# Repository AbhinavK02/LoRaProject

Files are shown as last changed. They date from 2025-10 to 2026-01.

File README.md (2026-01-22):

# LoRaProject
## Introduction
All people have a lot to do and may not always have time to check their mailbox.
Imagine how long some letters are left in the mailbox for days just because one is too busy. On the
other hand, checking your mailbox only to find nothing is quite frustrating. What if there was a way
that your mailbox could tell you when there is mail? What if you had a talking mailbox?
To solve this problem, we introduce The Talking Mailbox. The aim of The Talking Mailbox project
is to design and assemble a system that can detect the presence of mail within a mailbox and notify the owner of the mailbox.

The full project report can be found here: [Project Report](<Project Report - Talking Mailbox.pdf?raw=true>)

Talking Mailbox Product Showcase (https://www.youtube.com/watch?v=1nNW60RcUi4)

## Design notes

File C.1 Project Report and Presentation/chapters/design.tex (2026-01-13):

\section{Methodology and Design}
\label{sec: methodologyAndDesign}
%%%%%%%%%%%%%%%%%%%%%%%%%%%%%%%%%%%%%%%%%%%%%%%%%%%%%%%%%%%%%%%%%%%%%%%%%%%%%%%%%%%%%%%%%%%%%%%%%%%%%%%%%%%%%%%%%%%%%%%%
% \subsection{Design Approach}
% \label{sec: designApproach}
% The design approach used in this project was a simple waterfall model. After a deliverable was completed, the next deliverable was started. This can be clearly seen in Figure \ref{fig: ganttChart}. The only exception to this model was during the Software Development and Project Implementation Deliverables (which are discussed in Section \ref{sec: implementation}) where some iterative testing and debugging was employed. The testing methods are discussed in Section \ref{sec: validationMethod}.
%%%%%%%%%%%%%%%%%%%%%%%%%%%%%%%%%%%%%%%%%%%%%%%%%%%%%%%%%%%%%%%%%%%%%%%%%%%%%%%%%%%%%%%%%%%%%%%%%%%%%%%%%%%%%%%%%%%%%%%%
\subsection{System Layer}
\label{sec: systemLayer}

\subsubsection{System Architecture}
The complete functional structure diagram of the system is shown in \ref{fig: fsd}. This illustrates the highest level of the systems design and the different modules which were created to fulfil the requirements. The complete design and revision history can also be found in the project repository on GitHub following this link \url{https://github.com/AbhinavK02/LoRaProject}.
\label{sec: systemArchitechture}
\begin{figure}[h!]
    \centering
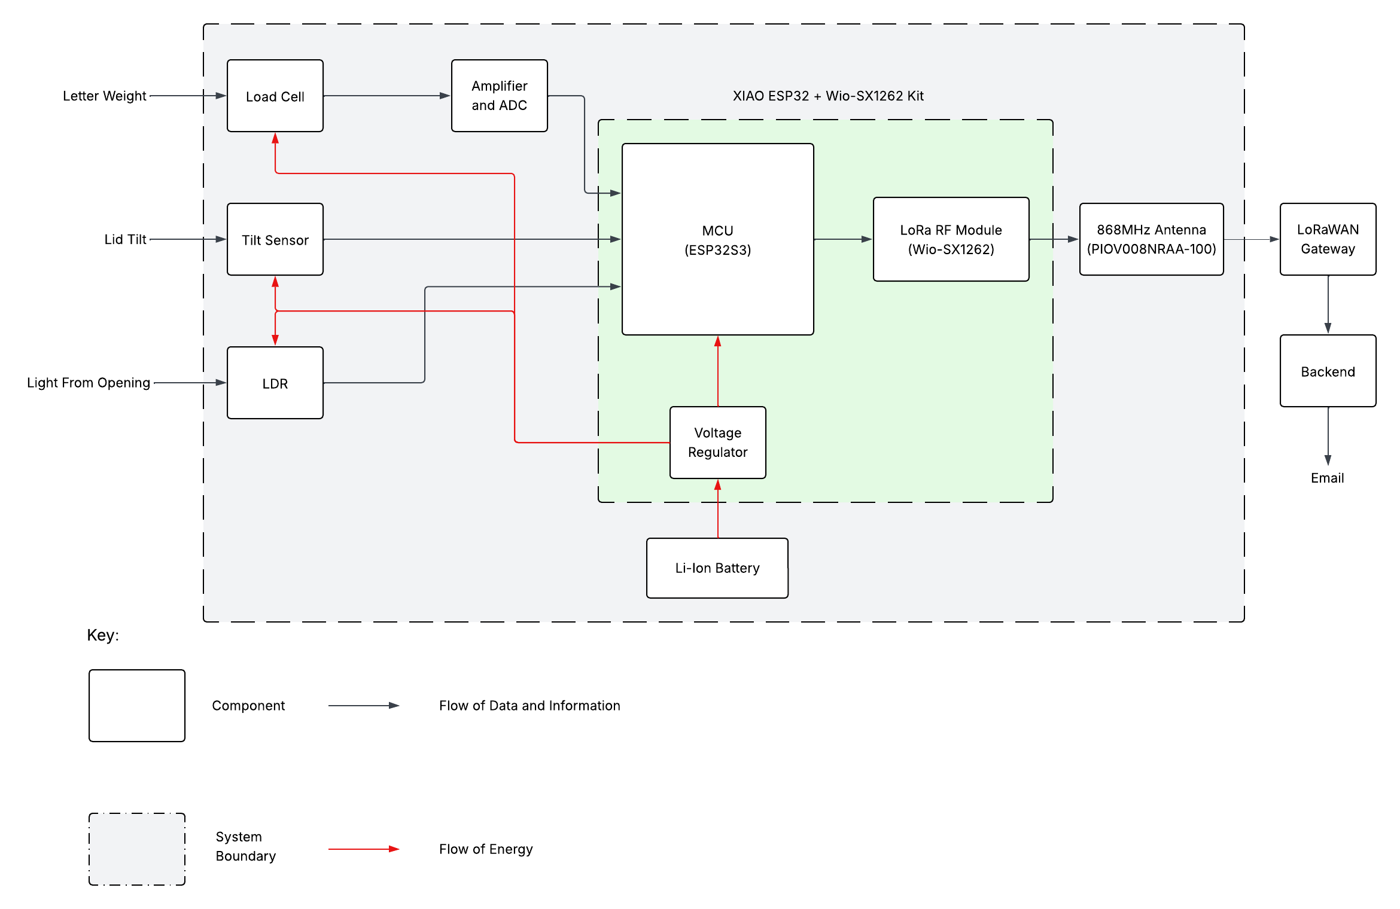
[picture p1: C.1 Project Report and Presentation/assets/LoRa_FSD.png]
    
    \caption{Functional Structure Diagram of the System Architecture}
    \label{fig: fsd}
\end{figure}
\pagebreak

\subsubsection{Bill of Materials}
\label{sec: billOfMaterials}
This is an estimate of the materials required to make this project, these are all over estimates, as all components/materials except 2.1 - 2.6 were used from the university stock.
\begin{table}[h]
    \centering
    \begin{tabular}{|c|l|p{2.8cm}|c|l|r|}
        \hline
        \textbf{Item} & \textbf{Part} & \textbf{Description} & \textbf{Qty} & \textbf{Notes} & \textbf{Total Price (€)} \\ \hline
        
        \rowcolor[gray]{0.9} \multicolumn{6}{|l|}{\textbf{1.0 Mechanical Components}} \\ \hline
        1.1 & Top Plate & Detection Plate & 1 & Wood (40x30x0.5cm) & 5.00 \\ \hline
        1.2 & Bottom Plate & Base for load cell & 1 & Wood (15x15x0.5cm) & 3.00 \\ \hline
        1.3 & M4 Screw & Top plate screw & 2 & - & 1.00 \\ \hline
        1.4 & M5 Hex Nut & Height spacer nut & 4 & - & 0.50 \\ \hline
        1.5 & M5 Screw & Bottom plate screw & 2 & - & 1.00 \\ \hline
        1.6 & M6 Hex Nut & Height spacer nut & 4 & - & 0.50 \\ \hline
        1.7 & Misc. & Tape, Glue & - & - & 0.50 \\ \hline
        
        \rowcolor[gray]{0.9} \multicolumn{6}{|l|}{\textbf{2.0 Electrical Components}} \\ \hline
        2.1 & Load Cell + HX711 & Load cell + Amplifier module & 1 & JOY-IT & 6.40 \\ \hline
        2.2 & Tilt Switch & Ball tilt switch & 1 & IDUINO & 0.94 \\ \hline
        2.3 & LDR & Light resistor & 1 & SERTRONICS & 1.35 \\ \hline
        2.4 & Battery & 1800 mAh Li-Ion & 1 & SOLDERED & 10.24 \\ \hline
        2.5 & MCU + LoRa & Xiao ESP32 + SX1262 & 1 & Seeedstudio & 11.68 \\ \hline
        2.6 & Antenna & Long range antenna & 1 & Amphenol-SAA & 2.69 \\ \hline
        2.7 & 1 kOhm resistor & Through Hole & 1 & YAGEO & 0.10 \\ \hline
        2.8 & 2 kOhm resistor & Through Hole & 1 & YAGEO & 0.10 \\ \hline
        2.9 & Wires & Jumper wires of different length & - & - & 0.30 \\ \hline
        2.10 & Misc. & Breadboard, Wire Sleeves, Solder & - & - & 0.50 \\ \hline
        \hline
        \multicolumn{5}{|r|}{Tax (VAT 20\%)} & 9.16 \\ \hline
        \multicolumn{5}{|r|}{\textbf{Grand Total (€)}} & \textbf{54.96} \\ \hline
        % for any changes check and adjust the BOM excel file
    \end{tabular}
    \caption{Combined Mechanical and Electrical Bill of Materials with Total Cost}
    \label{tab: bom}
\end{table}

%%%%%%%%%%%%%%%%%%%%%%%%%%%%%%%%%%%%%%%%%%%%%%%%%%%%%%%%%%%%%%%%%%%%%%%%%%%%%%%%%%%%%%%%%%%%%%%%%%%%%%%%%%%%%%%%%%%%%%%%
\subsection{Hardware Layer}
\label{sec: HWLayer}
\subsubsection{Load Cell Assembly}
\label{sec: 3dDesign}
According to \citeA{joyit_hx711_loadcell}, to reliably detect any weight, the load cell must be allowed to bent as easily as possible and thus be secured within a platform. To prevent any mail from "missing" the detection platform, the platform must cover the entire box area. The design which allows this is shown in Figure \ref{fig: 3dModels}.

\begin{figure}[ht]
     \centering
     \begin{subfigure}{0.48\textwidth}
         \centering
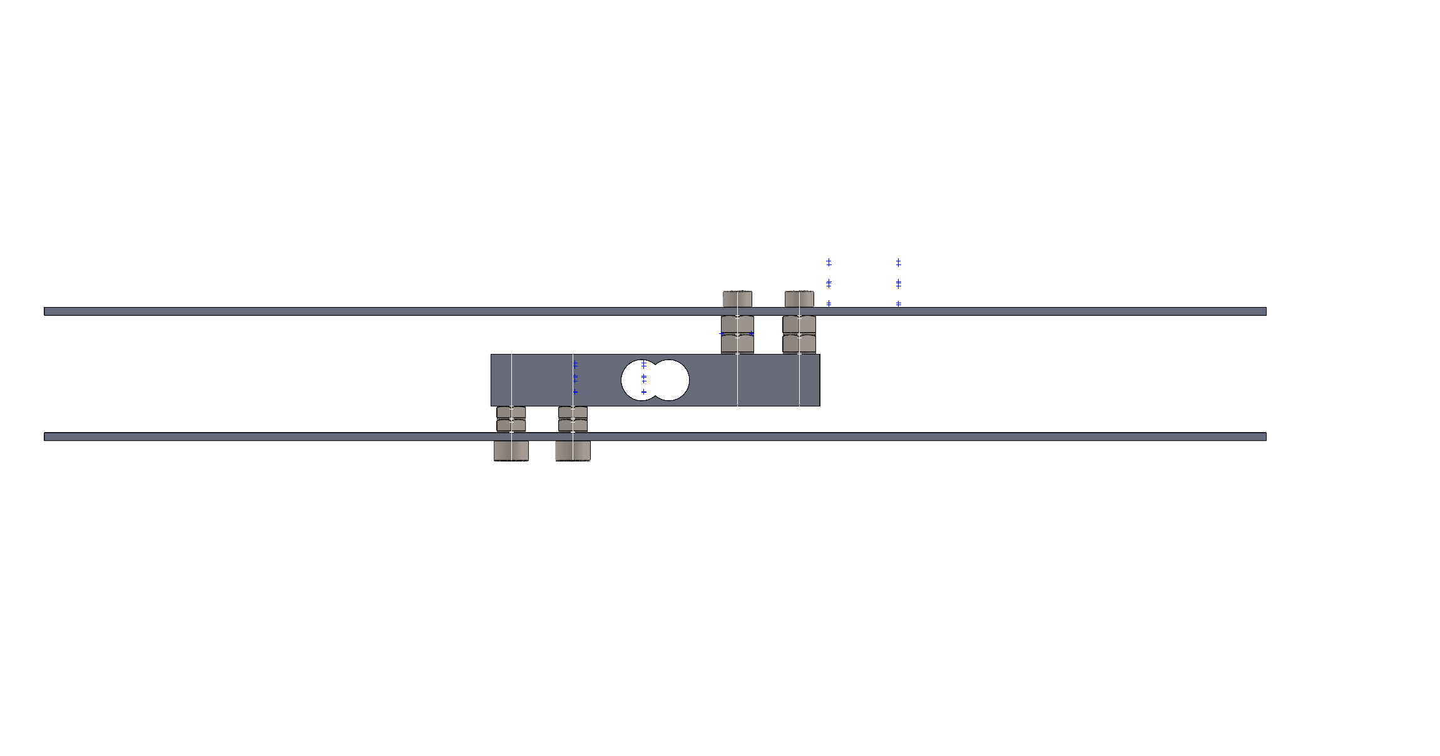
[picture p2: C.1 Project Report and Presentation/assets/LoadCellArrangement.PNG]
         
         \caption{3D Model of Load Cell Arrangement}
         \label{fig: loadCellArrangement}
     \end{subfigure}
     \hfill
     \begin{subfigure}{0.48\textwidth}
         \centering
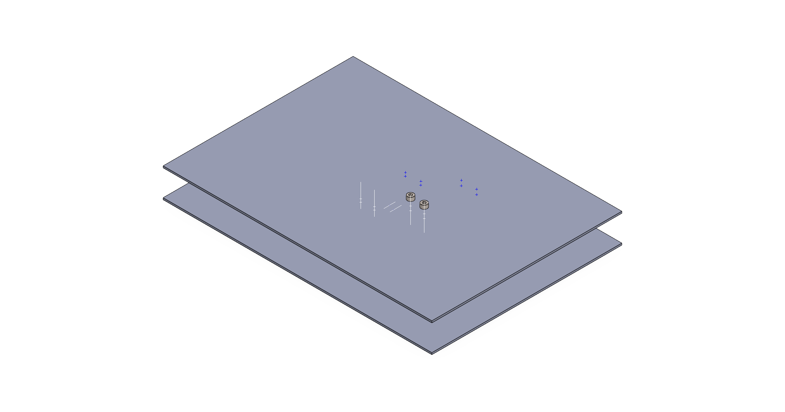
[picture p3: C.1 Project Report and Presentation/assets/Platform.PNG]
         
         \caption{Platform for mail detection}
         \label{fig: platform} 
     \end{subfigure}
     \caption{3D Model of detection platform}
     \label{fig: 3dModels}
\end{figure}
The height with the hex nuts, allow the load cell to have clearance to bend during load from the upper platform. The off center screw platform on both platform allow for best readings from the load cell. The size of the upper platform should match the post box size, however the lower platform allows for flexibility, it can be made just large enough to not cause toppling over and allow us to place necessary modules (such as the HX711). 

\bigskip

Some other design considerations include the requirement of the platform being rigid and lightweight, to allow load cell to be as sensitive as possible. A good material to use for the platform is wood. The screws should also be flat with the platform, to prevent mail from tearing / getting stuck. The process of assembling the load cell platform is shown in Figure \ref{fig: construction}.

\begin{figure}[ht]
    \begin{subfigure}{0.48\textwidth}
        \centering
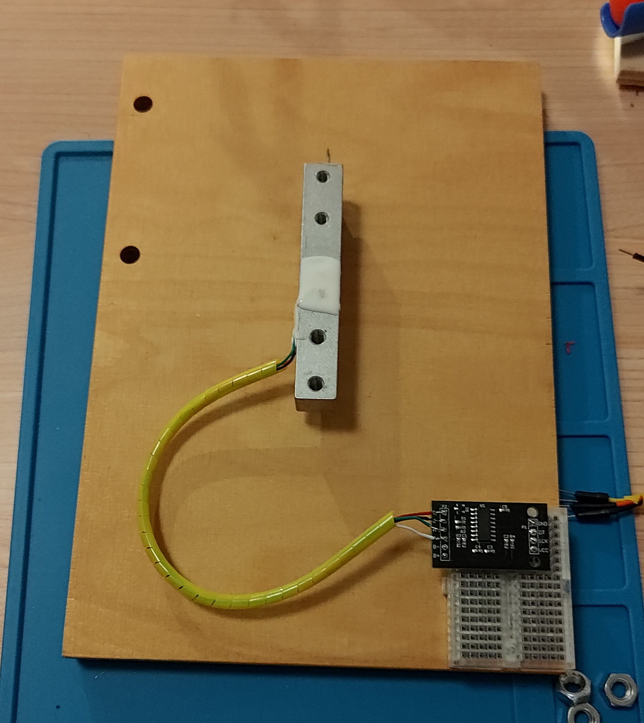
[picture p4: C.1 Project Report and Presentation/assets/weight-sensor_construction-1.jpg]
        
        \caption{Construction of Lower Platform}
        \label{fig: lowerConstruction}                   
    \end{subfigure}
    \begin{subfigure}{0.48\textwidth}
        \centering
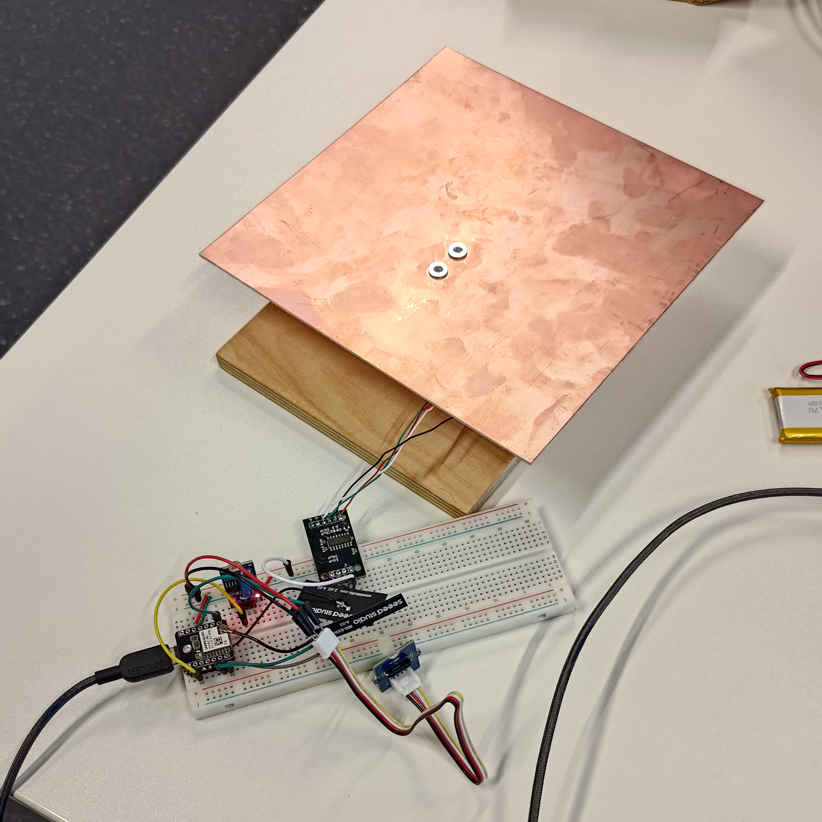
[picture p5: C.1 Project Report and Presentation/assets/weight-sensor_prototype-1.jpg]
        
        \caption{Load Cell Platform Prototype}
        \label{fig: constructionAssembled}                   
    \end{subfigure}
    \caption{Weight Sensor Construction}
    \label{fig: construction}
\end{figure}

The prototype shown in Figure \ref{fig: constructionAssembled} was then improved upon by increasing the size of the top platform to cover a greater area within the mailbox as well as adding a backboard to ensure mail does not slide off of the platform when the mailbox is opened. The final design is shown in Figure \ref{fig: finalProduct}.
% \subsubsection{Sensor Selection}
% \label{sec: sensorSelection}
% The sensors selected for this project were based on the functional requirements defined in Section \ref{sec: projectRequirements} as well as the shortcomings discussed in Section \ref{sec: literatureReview}. The general idea was to use multiple sensors to detect the same event, in order to increase reliability as well as a sensor which can detect not only events, but the current status of the mailbox. Hence, the light sensor and tilt sensor combination was chosen to detect the opening of the mailbox, while the load cell was chosen to detect the presence of mail. The reasons for choosing these specific sensors and their principle of operation are discussed in Section \ref{sec: sensors}.

\subsubsection{Schematic Design}
\label{sec: schematicDesign}
The complete schematic design of the system is shown in Figure \ref{fig: schematic}. The design is quite simple as the light and tilt sensors are digital sensors and connect directly to any GPIO pins on the microcontroller. The load cell on the other hand connects to the HX711 amplifier board, which then has a data line and clock line connecting to the ESP32-S3. The SX1262 LoRa module is connected via SPI, but the depiction in Figure \ref{fig: schematic} is a bit inaccurate. The kit comes with B2B connection which allows the MCU and LoRa module to be connected directly without any wiring. The pin mapping between the sensors and the microcontroller is shown in Table \ref{tab: pin-mapping}.

\begin{table}[h]
    \centering
    \begin{tabular}{|l|l|}
        \hline
        \textbf{Sensor Pin} & \textbf{ESP32-S3 Pin} \\ \hline
        Tilt Sensor DO      & GPIO1  \\ \hline
        Battery Monitor     & GPIO2  \\ \hline
        Light Sensor DO     & GPIO3  \\ \hline
        HX711 CLK           & GPIO6  \\ \hline
        HX711 DAT           & GPIO43 \\ \hline
        SX1262 SCK          & GPIO7  \\ \hline
        SX1262 MISO         & GPIO8  \\ \hline
        SX1262 MOSI         & GPIO9  \\ \hline
    \end{tabular}
    \caption{Sensor-to-ESP32-S3 Pin Mapping}
    \label{tab: pin-mapping}
\end{table}

\begin{figure}[H]
    \centering
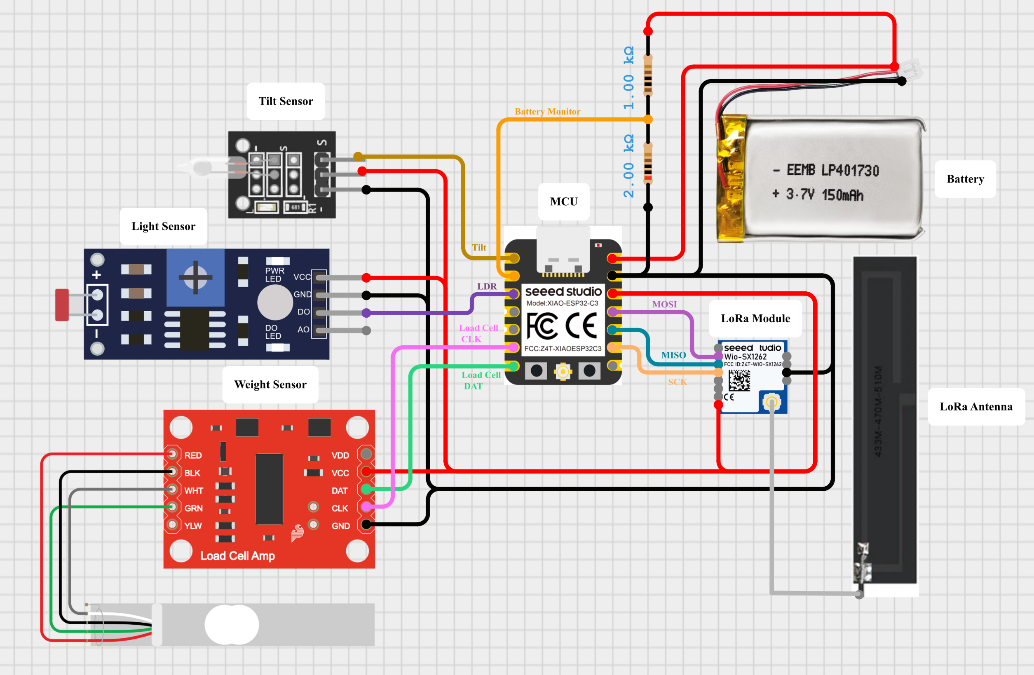
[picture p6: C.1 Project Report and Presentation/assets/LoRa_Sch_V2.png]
    
    \caption{Schematic Diagram of the System}
    \label{fig: schematic}
\end{figure}
%%%%%%%%%%%%%%%%%%%%%%%%%%%%%%%%%%%%%%%%%%%%%%%%%%%%%%%%%%%%%%%%%%%%%%%%%%%%%%%%%%%%%%%%%%%%%%%%%%%%%%%%%%%%%%%%%%%%%%%%
\subsection{Embedded Software Layer}
\label{sec: ESWLayer}
\subsubsection{System Flow}
\label{sec: systemFlow}
The complete logical flow of the system is illustrated in \ref{fig: programmingFlowChart}. 
\begin{figure}[H]
    \centering
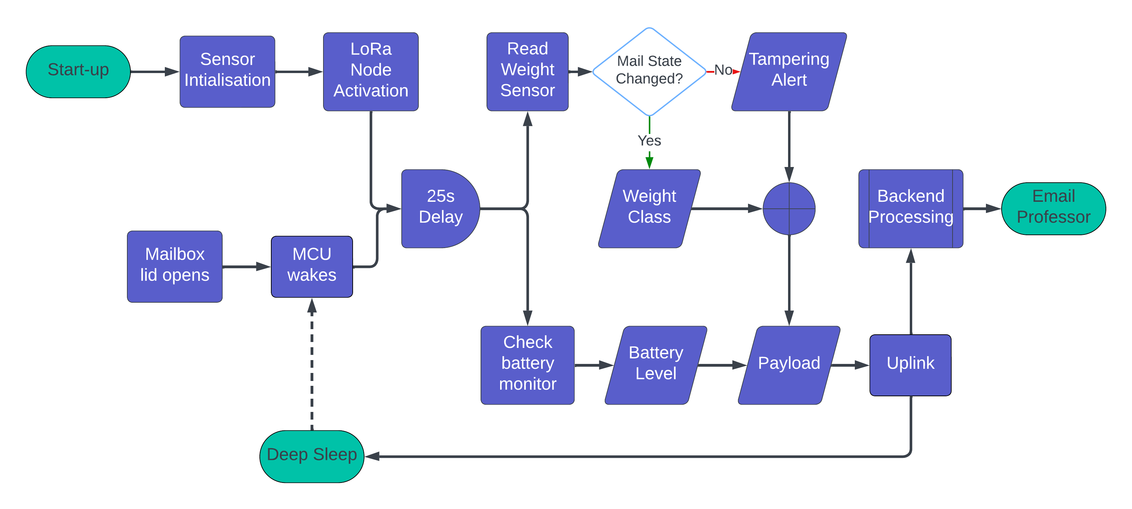
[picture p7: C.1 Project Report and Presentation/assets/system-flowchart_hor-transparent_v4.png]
    
    \caption{Programming Flow Chart of the Embedded Software}
    \label{fig: programmingFlowChart}
\end{figure}

The general idea is that upon start-up, the sensors are initialised, the LoRaWAN node is activated, the mail detection logic is executed to build the payload, the payload is transmitted and the controller is put to sleep. Once the light or tilt sensor is triggered, the ESP32-S3 wakes up and the process repeats. 

\bigskip

The actual execution of this flow is implemented in the \textbf{LR-V1.0.ino} as shown in Listing \ref{lst: mainCode}. All of the functions used are defined and explained in the subsequent sections.
\begin{lstlisting}[language=C++, caption={Main Code in LR-V1.0.ino}, label={lst: mainCode}]
#include "LoRaConfig.h"
#include "SensorManager.h"
// Start Here upon Wake-up
void setup() {
  Serial.begin(115200);

  // Initialising all the Sensors
  sensorManager_init();

  // Radio Setup
  Serial.println(F("\nSetup... "));

  ...

  // Activating the node for LoRaWAN
  state = lwActivate();
  Serial.println(F("Ready!\n")); // Ready to begin uploading

  // Reading Sensors and Building in Payload
  uplinkPayloadLen = detectMail(uplinkPayload);

  // Uploading the Payload
  state = lwUplink(uplinkPayload);

  delay(5000);

  // Sleep
  radio.sleep();
  goToSleep();
}
void loop() {
  // Empty since sleep interrupt operates as the loop
}
\end{lstlisting}

\subsubsection{Microcontroller Code Structure}
\label{sec: microcontrollerCodeStructure}

The microcontroller code was structured with modularity in mind and divided into four files: 
\begin{itemize}
    \item \textbf{SensorManager.cpp:} This file contains all the functions related to sensor initialization, reading sensor values, and processing the sensor data.
    \item \textbf{SensorManager.h:} This is the header file for SensorManager.cpp, containing function prototypes and necessary libraries and macros.
    \item \textbf{LoRaConfig.h:} This file handles the LoRaWAN communication, initializing required parameters, including libraries, defining functions for LoRa activation and upload.
    \item \textbf{LR-V1.0.ino:} This is the main file which essentially just runs the functions defined in the preceding files in the specific order required. 
\end{itemize}

To program the ESP32-S3, the Arduino IDE was used. The complete code can be found in the project repository (or in the attached zip file). Additionally, all libraries required are also included in the repository for ease of access. Simply click on File \textgreater{} Preferences and change the sketchbook location to the path of the project repository. The ESP32 board manager must also be installed following the instructions from \href{https://docs.espressif.com/projects/arduino-esp32/en/latest/installing.html}{Express-If Documentation}. Once installed, select "XIAO\_ESP32S3" from Tools \textgreater{} Board menu.

\subsubsection{Sensor Management}
\label{sec: sensorManager}
To initiliase the pins and parameters of the sensors, the \cmd{sensorManager_init()} function was defined as shown in Listing \ref{lst: sensorManagerInit} from the \textbf{SensorManager.h} file.

\begin{lstlisting}[language=C++, caption={sensorManager\_init() Function}, label={lst: sensorManagerInit}]
void sensorManager_init(){
  // Weight Sensor
  scale.begin(LOADCELL_DOUT_PIN, LOADCELL_SCK_PIN); // initiliase weight sensor
  scale.set_scale(883.f);                           // Set the default (calibrated against scale)
  scale.power_down();                               // Put HX711 to sleep to save power
  delay(2000);
  SensorReading weightReading = readWeightSensor();
  weightState_prev = weightReading.value; // initial weight state

  // Light Sensor
  pinMode(LIGHT_SENSOR_PIN, INPUT); // Input mode for light sensor

  // Tilt Sensor
  pinMode(TILT_SENSOR_PIN, INPUT); // Input mode for tilt sensor

  // Setting up ADC for Battery Monitor
  analogReadResolution(12);       // 0 to 4095
  analogSetAttenuation(ADC_11db); // Allows full 0 to 3.3V range

  // End Intialisation
  Serial.println("Sensor Manager Initialized.");
}
\end{lstlisting}

Importantly, this function sets the scale factor for the load cell after calibration and configures the ADC for battery monitoring. The process of calibration is discussed in Section \ref{sec: weightSensorImplementation}. The ADC is set to 12-bit resolution to allow readings from 0 to 4095, and the attenuation is set to 11dB to allow the full voltage range of 0 to 3.3V to be read instead of the default 1.1V. The function also puts the HX711 load cell amplifier to sleep after initialization to save power.

\bigskip

Additionally, to keep the sensor readings organised, a struct called \cmd{SensorReading} was created. This struct contains the value read from the sensor as well as an identifying number. This is useful for logging and debugging purposes. The struct is defined in Listing \ref{lst: sensorReadingStruct} from the \textbf{SensorManager.h} file.

\begin{lstlisting}[language=C++, caption={sensorReading struct}, label={lst: sensorReadingStruct}]
struct SensorReading
{
    uint8_t id;    // Unique for each sensor ID
    uint8_t value; // The actual value
};
\end{lstlisting}

\subsubsection{Weight Sensor Implementation}
\label{sec: weightSensorImplementation}
To use the HX711 load cell amplifier, the HX711 library (V0.7.5) by Bogdan Necula was used. This library provides an easy to use interface for reading values from the load cell. 

\bigskip

Before using the load cell, it must be calibrated. This was done by weighing an object with a calibrated scale and then placing it on the load cell. The ESP32-S3 was programmed to tare the scale and then call the function \cmd{scale.get_units(10)} to get the average of 10 readings from the load cell. This value is then divided by the known weight to get the scale factor. After multiple iterations, a scale factor of 883.f was found to be accurate for this setup. This value was then set during initialization as shown in Listing \ref{lst: sensorManagerInit}. 

\bigskip

The actual reading of the weight sensor is done in the \cmd{readWeightSensor()} function defined in the \textbf{SensorManager.cpp} file. The function first wakes up the HX711 from sleep mode, reads the weight value and compares against predefined thresholds to determine if a light, medium, or heavy package is present. The most important line is  where the load cell value is read as shown in Listing \ref{lst: readWeightSensor}. The average of 10 values are taken and normalised by subtracting the tare value of 270 (the reading when no weight is present). This was done instead of the \cmd{scale.tare()} function from the HX711 library because running the tare function would require the user to ensure no weight is present either upon startup/wake-up or before every reading which is not feasible for this application. While this is certainly possible during initial installation and start up, every time the ESP32 wakes from deep sleep it would tare the load cell and thus ignore any mail which was placed while the device was asleep. 

\begin{lstlisting}[language=C++, caption={Excerpt ofreadWeightSensor() Function}, label={lst: readWeightSensor}]
SensorReading readWeightSensor() {
  scale.power_up(); // Wake HX711 from sleep
  ...

  if (scale.is_ready()) {
    weight = scale.get_units(10) - 270; // Normalised Average of 10 readings (based on calibration)
    ...
  } else {
    Serial.println("HX711 not found.");
  }

  reading.value = (uint8_t)weightState; // storing state value

  scale.power_down(); // Put HX711 to sleep to save power
  delay(500);
  return reading;
}
\end{lstlisting}

\subsubsection{Battery Monitor Implementation}
A battery monitor was implemented using the \cmd{batteryMonitor()} function defined in the \textbf{SensorManager.cpp} file and shown in Listing \ref{lst: batteryMonitor}. From Figure  \ref{fig: schematic}, we can see a voltage divider is used because the maximum battery voltage of 4.2V, which exceeds the maximum input voltage of the ESP32-S3 (3.3V). This is compensated for in the code by the multiplication of the \cmd{adcVoltage} by the voltage divider ratio, which in this case is 1.5. The function then maps the voltage linearly to a percentage based on the operating voltage range of 3.1V (0\%) to 4.2V (100\%) to give the user an easily readable indication of the battery level. 

\begin{lstlisting}[language=C++, caption={batteryMonitor() Function}, label={lst: batteryMonitor}]
SensorReading batteryMonitor() {
  SensorReading reading;
  uint8_t batPercentage;
  reading.id = ID_BAT_MONITOR;
  int adcValue = analogRead(BAT_MONITOR_PIN);
  float adcVoltage = (adcValue * 3.3) / 4095; // Calculating U[V] at the pin
  float batVoltage = adcVoltage * 1.5; // Using ratio to find actual U[V]
  if (batVoltage >= 4.20) { //4.20V ^= 100%
    reading.value = 100;
  } else if (batVoltage <= 3.10) { //3.10V ^= 0%
    reading.value = 0;
  } else { // Mapping to percentage
    batPercentage = (batVoltage - 3.10) * 100 / (1.1); 
    reading.value = batPercentage;
  }
  return reading;
}
\end{lstlisting}

\subsubsection{Mail Detection logic}
\label{sec: mailDetectionLogic}
With all the sensors setup, detecting the state of the mailbox is handled by the \cmd{detectMail()} function found in \textbf{SensorManager.cpp}. The function first reads the weight sensor to determine if there is mail present, then checks for tampering by comparing the current weight state with the previous one. If no change is detected, it indicates that the lid was opened, but no mail was added or removed which by our logic means someone is looking into the mailbox for potentially nefarious reasons. If a change is detected, the function encodes the type of mail detected based on the weight state from the \cmd{readWeightSensor()} function. The function's argument is a pointer to a payload buffer where the encoded data is stored for transmission via LoRaWAN. Thus the actual encoding process is as simple as adding the relevant information into the buffer with a line like \cmd{payloadBuffer[len++] = ID;}. 

\bigskip

One significant feature of this function is a 25 second delay implemented before the weight sensor is read to ensure the mail person has sufficient time to place all the mail onto the platform. This was added after testing showed that the load cell could miss mail events if not placed quickly enough as discussed in Section \ref{sec: emailNotificationResults}. 

% \begin{lstlisting}[language=C++, caption={detectMail() Function}, label={lst: detectMail}]
% uint16_t detectMail(uint8_t *payloadBuffer) {
%   uint16_t len = 0;
%   payloadBuffer[len++] = ID_DEVICE;                 // Device ID
%   delay(25000);                                     // Wait for mail to be placed
%   SensorReading weightReading = readWeightSensor(); // read the weight sensor value
%   SensorReading batteryReading = batteryMonitor();  // read the battery voltage
%   weightState_curr = weightReading.value;           // Set current state from reading
%   if (weightState_curr == weightState_prev) { // if no change, then someone is peaking
%     Serial.println("Tampering Detecting");
%     payloadBuffer[len++] = ID_TAMPERING; // Encode Tampering code
%   } else { // If state changed, look at the mail status
%     Serial.print("Mail was ");
%     Serial.println(weightState_curr > weightState_prev ? "Added" : "Removed"); // Mail is there?
%     switch (weightState_curr) {
%         case 3:
%             payloadBuffer[len++] = ID_HEAVY_MAIL;
%             break;
%         case 2:
%             payloadBuffer[len++] = ID_MEDIUM_MAIL;
%             break;
%         case 1:
%             payloadBuffer[len++] = ID_LIGHT_MAIL;
%             break;
%         case 0:
%             payloadBuffer[len++] = ID_NO_MAIL;
%             break;
%     }
%   }
%   // Also add the battery voltage into the payload
%   payloadBuffer[len++] = batteryReading.id;
%   payloadBuffer[len++] = batteryReading.value;
%   weightState_prev = weightState_curr; // update weight state
%   Serial.println();
%   return len;
% }
% \end{lstlisting}

\subsubsection{Wake-up and Sleep Logic}
In an effort to save as much power as possible, the ESP32-S3 is put into sleep mode after each mail detection session and transmission. This is done using the function \cmd{goToSleep()} defined in \textbf{SensorManager.cpp} and shown in Listing \ref{lst: goToSleep}. This function configures the wake-up sources to be the light sensor and tilt sensor pins, such that when either of these pins goes low (indicating the mailbox lid is opened or light is detected inside the mailbox), the ESP32 will wake up from deep sleep. 
\begin{lstlisting}[language=C++, caption={goToSleep() Function}, label={lst: gotToSleep}]
void goToSleep() {
  Serial.println("Going to deep sleep...");

  // Configure Wake Interrupt
  esp_sleep_enable_ext1_wakeup((1ULL << LIGHT_SENSOR_PIN) | (1ULL << TILT_SENSOR_PIN), ESP_EXT1_WAKEUP_ANY_LOW);

  // Sleep
  Serial.flush();
  esp_deep_sleep_start();
}
\end{lstlisting}

\subsubsection{LoRaWAN Configuration}
\label{sec: loraConfig}
All of the configuration and functions required for LoRaWAN communication are defined in the \textbf{LoRaConfig.h} file. The libraries required are RadioLib (V7.4.0) by Jan Gromes and Preferences (installed in Arduino IDE by default). The configuration process was also completed with guidance from \citeA{wio_sx1262_xiao_esp32s3_lora_node}.

\bigskip

The first and most important step is defining the access keys for The Things Network (TTN). Setting up a device on TTN is discussed in Section \ref{sec: ttnConfiguration}, but once the device is created, the keys can be found in the console. These keys were first defined as macros for easy access and then copied into variables for use as shown in Listing \ref{lst: ttnKeys}.

\begin{minipage}{\textwidth}
    \begin{lstlisting}[language=C++, caption={TTN Key Definition}, label={lst: ttnKeys}][float]
    // TTN Keys for Accessing the Network
    #ifndef RADIOLIB_LORAWAN_JOIN_EUI // All zeros for TTN compliance
    #define RADIOLIB_LORAWAN_JOIN_EUI 0x0000000000000000
    #endif

    #ifndef RADIOLIB_LORAWAN_DEV_EUI
    #define RADIOLIB_LORAWAN_DEV_EUI 0x070B3D57ED0074D0
    #endif

    #ifndef RADIOLIB_LORAWAN_APP_KEY
    #define RADIOLIB_LORAWAN_APP_KEY 0x02, 0xBC, 0xE7, 0xC1, 0x02, 0xB3, 0x18, 0xD7, 0x02, 0xF2, 0x18, 0xDF, 0x9E, 0x45, 0xD1, 0x8E
    #endif

    ...

    // Copy over Keys
    uint64_t joinEUI = RADIOLIB_LORAWAN_JOIN_EUI;
    uint64_t devEUI = RADIOLIB_LORAWAN_DEV_EUI;
    uint8_t appKey[] = {RADIOLIB_LORAWAN_APP_KEY};
    \end{lstlisting}
\end{minipage}

After the keys are set, the LoRa node is activated using the function \cmd{lwActivate()} found in the \textbf{LoRaConfig.h} file. The Over the Air Activation (OTAA) method is used instead of the Activation By Personalization (ABP) method for better security and flexibility. This is done using the RadioLib command \cmd{node.activateOTAA()} as shown in Listing \ref{lst: ttnJoinFresh}. Because this process sometimes fails due to network issues or recognition issues on the TTN side, a loop is implemented to retry joining until successful.

\begin{lstlisting}[language=C++, caption={TTN Joining Loop in lwActivate()}, label={lst: ttnJoinFresh}]
while (state != RADIOLIB_LORAWAN_NEW_SESSION) {
    Serial.println(F("Joining LoRaWAN fresh..."));
    state = node.activateOTAA();

    // Storing Nonces
    uint8_t *persist = node.getBufferNonces();
    memcpy(lwNonces, persist, RADIOLIB_LORAWAN_NONCES_BUF_SIZE);
    store.putBytes("nonces", lwNonces, RADIOLIB_LORAWAN_NONCES_BUF_SIZE);

    if (state == RADIOLIB_LORAWAN_NEW_SESSION)
        break;

    // Fail and Retry
    Serial.print(F("Join failed: "));
    Serial.println(state);
    delay(5000); // Retry every 5s
}
Serial.println(F("Join successful"));
\end{lstlisting}

To make re-joining faster on subsequent wake-ups and power cycles, the nonces are stored in the ESP32's non-volatile memory (NVM) using the Preferences library as shown in Listing \ref{lst: ttnJoinFresh}. Once the nonces are restored, the node attempts to re-join in a loop until successful, after which the new nonces are stored. This solved the major rejoining issue discussed in Section \ref{sec: ttnRejoinIssue}. Additionally, the session is also stored in the RTC memory allowing for even faster re-joining after deep sleep wake-ups. This is done because storing sessions indefinitely within the NVM may lead to unnecessary wear on the memory. This re-joining process is shown in Listing \ref{lst: ttnReJoin}. Notice that the program checks if restoring the session is possible first before looping through the nonces. This solution was adapted from example code from \citeA{radiolibpersistence_lorawan_esp32}.

\begin{minipage}{\textwidth}
    \begin{lstlisting}[language=C++, caption={TTN Re-Joining Loop using Stored Nonces or Session in TTN Joining Loop in lwActivate()}, label={lst: ttnReJoin}]
    // Restore nonces from NVM
    store.getBytes("nonces", lwNonces, RADIOLIB_LORAWAN_NONCES_BUF_SIZE);
    state = node.setBufferNonces(lwNonces);
    debug(state != RADIOLIB_ERR_NONE, F("Restoring nonces failed"), state, false);

    // Restore session from RTC
    state = node.setBufferSession(lwSession);

    // Joining TTN (if restore not immediate)
    while (state != RADIOLIB_LORAWAN_NEW_SESSION) {
        Serial.println(F("Joining LoRaWAN..."));
        state = node.activateOTAA();
        if (state == RADIOLIB_LORAWAN_SESSION_RESTORED) {
            Serial.println(F("LoRaWAN session restored"));
            break;
        } else if (state == RADIOLIB_LORAWAN_NEW_SESSION) {
            Serial.println(F("Join successful, saving nonces"));
            uint8_t *persist = node.getBufferNonces();
            Serial.print("Dev Nonces: ");
            Serial.println((char *)persist);
            memcpy(lwNonces, persist, RADIOLIB_LORAWAN_NONCES_BUF_SIZE);
            store.putBytes("nonces", lwNonces, RADIOLIB_LORAWAN_NONCES_BUF_SIZE);
            break;
        }
        Serial.print(F("Join failed: "));
        Serial.println(state);
        delay(5000); // Retry every 5s
    }
    \end{lstlisting}
\end{minipage}
\subsubsection{LoRaWAN Data Transmission}
The actual transmission of data via LoRaWAN is handled by the \cmd{lwUplink()} function defined in the \textbf{LoRaConfig.h} file. This function transmits the payload encoded in the \cmd{detectMail()} function using the RadioLib command \cmd{node.sendReceive(uplinkPayload, uplinkPayloadLen)}. Similar to in the joining process in in Listing \ref{lst: ttnJoinFresh}, the function loops to until the data is successfully sent. 
%%%%%%%%%%%%%%%%%%%%%%%%%%%%%%%%%%%%%%%%%%%%%%%%%%%%%%%%%%%%%%%%%%%%%%%%%%%%%%%%%%%%%%%%%%%%%%%%%%%%%%%%%%%%%%%%%%%%%%%%
\subsection{Transport Layer}
\label{sec: transportLayer}
\subsubsection{TTN Configuration}   
\label{sec: ttnConfiguration}
To set up the device on The Things Network (TTN), first an account was created on \href{https://www.thethingsnetwork.org/}{The Things Network}. After logging in, a new application and end-device were created. The end-device was configured with a Join EUI of all zeros to comply with TTN's non-commercial regulations and the Europe 868.1 MHz frequency plan since the device is being developed in Germany. Most importantly, the LoRaWAN specification was set to 1.0.4 as it is the most up-to-date and RadioLib V7.4.0 is designed to comply with the specifications. 
%%%%%%%%%%%%%%%%%%%%%%%%%%%%%%%%%%%%%%%%%%%%%%%%%%%%%%%%%%%%%%%%%%%%%%%%%%%%%%%%%%%%%%%%%%%%%%%%%%%%%%%%%%%%%%%%%%%%%%%%
\subsection{Application Layer}

This section covers the implementation of the backend server and application layer, which is responsible for receiving data from The Things Network, decoding the payload, storing the data, and providing a user interface for monitoring the mailbox status.
The link with the The Things Network is done using webhooks, which send HTTP POST requests to the python server whenever new data is received from the LoRaWAN device.

\subsubsection{Backend Server Setup}
\label{sec: initalSetup}
To set up the backend server, we require three files, which include: 'server.py', '.env', and 'requirements.txt'. Each file servers a specific purpose:
\begin{itemize}
    \item \textbf{server.py:} This is the main server file that contains the Flask application code. It handles incoming requests, decodes the payload, updates the mailbox status, and serves the user interface.
    \item \textbf{.env:} This file contains environment variables such as server port, authentication token, email sender credentials, and recipient email addresses. This allows for easy configuration without hardcoding sensitive information in the code.
    \item \textbf{requirements.txt:} This file lists all the Python libraries required to run the server. 
\end{itemize}
These all need to be placed in the same directory for the server to function correctly. The server can then be started by running the command `python server.py` in the terminal.
The dependencies, to be added to requirements.txt as shown in Listing \ref{lst: requirementstxt}, can be installed using the command `pip install -r requirements.txt`.
\begin{lstlisting}[caption={requirements.txt file contents}, label={lst: requirementstxt}]
Flask==2.3.3
python-dotenv==1.0.0
\end{lstlisting}
These can be installed directly using pip as well, however using requirements.txt makes it easier and more future proof. These steps can be also be avoided, and the bash script from Section \ref{sec: issuesWithStaticIPAndHosting} be used directly to install the required
libraries if they are missing.

\smallskip

Next a random authentication token must be generated, for Windows 11, the command shown in Listing \ref{lst: generateAuthToken} can be used.
\begin{lstlisting}[language=bash, caption={Generate random auth token command}, label={lst: generateAuthToken}]
$bytes = New-Object byte[] 16; (New-Object System.Security.Cryptography.RNGCryptoServiceProvider).GetBytes($bytes);
[System.BitConverter]::ToString($bytes) -replace '-'
\end{lstlisting}

Now you can open the .env file using a text editor of your choice (here edit by MS was used). The following variables must be
added as shown in Listing \ref{lst: envFileContents}:
\begin{lstlisting}[caption={.env file contents}, label={lst: envFileContents}]
export SERVER_PORT=3000
export AUTH_TOKEN=<token from above>

EMAIL_SENDER=your_email@gmail.com
EMAIL_PASSWORD=your_app_password_here
\end{lstlisting}

The main contents of server.py are explained in the following sections and full code can be found in the project repository. 

\subsubsection{Payload Decoder}
\label{sec: payloadDecoder}
The LoRaWAN is able to send the bits to The Things Network. However for these to be actually useful to the user they must be 
decoded and used to represent relevant information for a user, this includes the mail status, the battery and which post box it is. For this first a payload decoder must be made. This is made keeping in mind how bits were encoded in the first place. The decoder can be seen in Listing \ref{lst: payloadDecoder}
\begin{lstlisting}[language=Python, caption={Payload Decoder Function}, label={lst: payloadDecoder}]
def decode_mailbox_data(base64_string):
    try:
        raw_bytes = base64.b64decode(base64_string)
        if len(raw_bytes) < 4:
            return None, "Error: Short Data", "red", None

        # 1. Decode ID (Hex to Int logic)
        try:
            device_id = int(f"{raw_bytes[0]:x}") 
        except:
            device_id = raw_bytes[0]

        state_byte = raw_bytes[1]
        value_id = raw_bytes[2]
        val = raw_bytes[3]

        # 2. Decode Status (Aligned with new JS Decoder)
        if state_byte == 0x04:
            status, color = "Tampering Alert", "red"
        elif state_byte == 0x05:
            status, color = "Heavy Mail", "#004d40" 
        elif state_byte == 0x06:
            status, color = "Medium Mail", "#00897b" 
        elif state_byte == 0x07:
            status, color = "Light Mail", "#4db6ac" 
        elif state_byte == 0x08:
            status, color = "No Mail", "blue"
        else:
            status, color = f"Unknown: {hex(state_byte)}", "orange"

        # 3. Decode Battery (valueID 0x09)
        battery = int((val/64)*100) if value_id == 0x09 else None
        # If battery, map it correct linear level (64 is 100%)
        return device_id, status, color, battery
            
    except Exception as e:
        logger.error(f"Decoding error: {e}")
        return None, "Decoding Failed", "black", None
\end{lstlisting}
This allows us to correctly identify if a heavy, medium or light package was detected. This information can then be used to update the website to represent the appropriate information and also be included in the mail sent to the user.

The key parts of the decoder are explained below:
\begin{itemize}
    \item "state\_byte" is used to determine the mail status, this is done by checking the value of the byte and mapping it to the appropriate status message.
    \item There is return at the start for robustness, in case the payload is too short or empty. 
    \item "value\_id" has been used as a form of future proofing, in case more values are added to the payload in the future.
\end{itemize}
For actual mapping of device ID to device name and email addresses, a dictionary is used as shown in Listing \ref{lst: deviceMapping}.
\begin{lstlisting}[language=Python, caption={Device mapping method}, label={lst: deviceMapping}]
    # --- Device Mapping ---
    DEVICE_NAMES = {
        33: "PostBox SAN"
        # Add more boxes here 
    }
    # --- Email Mapping ---
    DEVICE_RECIPIENTS = {
        33: "email1@gmail.com, email2@gmail.com"
        # Add more emails here
    }
\end{lstlisting}
More can be added as just new rows with the similar syntax just a comma at the end of all rows except the last one. 
Multiple email addresses can also be added by separating them with a comma within the double quotes.\\

\subsubsection{Frontend Implementation}
\label{sec: frontendImplementation}
For the actual server, which the user interacts, with a python server was created. This server uses the Flask framework to create a simple web application that displays the status of the mailbox. 
The server listens for incoming data from The Things Network and updates the mailbox status accordingly. The relevant code snippet is shown in Listing \ref{lst: flaskServer}
\begin{lstlisting}[caption={Flask Server Code Snippet}, label={lst: flaskServer}]
@app.route('/', methods=['GET'])
def show_dashboard():
    d = dashboard_data
    html = """
    <!DOCTYPE html>
    <html>
    <head>
        <title>Mailbox Monitor</title>
        <meta http-equiv="refresh" content="5">
        <style>
            body {  
                font-family: 'Segoe UI', sans-serif; 
                text-align: center; 
                padding: 40px; 
                background-color: #f0f2f5; }
            .card { 
                background: white; 
                padding: 40px; 
                border-radius: 15px; 
                display: inline-block; 
                box-shadow: 0 4px 12px rgba(0,0,0,0.1);                     
                width: 450px; }
            .status-box {   
                font-size: 32px;                         
                font-weight: bold; 
                margin: 20px 0; 
                padding: 20px; 
                color: white; 
                border-radius: 10px; 
                background-color: {{ d.status_color }}; }
            .battery-indicator { 
                font-weight: bold; 
                font-size: 18px; 
                padding: 5px 15px; 
                border-radius: 20px; 
                display: inline-block; 
                color: white; 
                background-color: {{ d.battery_color }}; }
            .meta { 
                color: #888; 
                font-size: 13px; 
                margin-top: 15px; }
            table { 
                width: 100%; 
                border-collapse: 
                collapse; 
                margin-top: 20px; 
                text-align: left; }
            th, td { 
                padding: 10px; 
                border-bottom: 1px 
                solid #eee; 
                font-size: 14px; }
            .dot { 
                height: 10px; 
                width: 10px; 
                border-radius: 50%; 
                display: inline-block; 
                margin-right: 5px; }
        </style>
    </head>
    <body>
        <div class="card">
            <h1>Smart Mailbox</h1>
            <h2 style="color:#666">{{ d.device_name }}</h2> 
            <div class="status-box">{{ d.status_text }}</div>
            <div class="battery-indicator">{{ d.battery_level }}</div>
            <p class="meta">Last Update: {{ d.timestamp }}</p>
            <h3>Recent Activity</h3>
            <table>
                <tr><th>Time</th><th>Event</th><th>Bat</th></tr>
                {% for event in d.history %}
                <tr>
                    <td>{{ event.time }}</td> 
                    <td>
                        <span class="dot" 
                            style="background-color: {{ event.color }};">
                        </span>{{ event.status }}</td>
                    <td>{{ event.battery }}</td>
                </tr>
                {% endfor %}
            </table>
        </div>
    </body>
    </html>
    """
    return render_template_string(html, d=d)
\end{lstlisting}

The final website can be run by just running the bash file and afterwards going to this link: \textbf{\href{https://unarithmetically-peppiest-libbie.ngrok-free.dev }{Smart Mailbox Dashboard}}

%%%%%%%%%%%%%%%%%%%%%%%%%%%%%%%%%%%%%%%%%%%%%%%%%%%%%%%%%%%%%%%%%%%%%%%%%%%%%%%%%%%%%%%%%%%%%%%%%%%%%%%%%%%%%%%%%%%%%%%%
\subsection{Validation Methods}
\label{sec: validationMethods}
During the development of the system, it became essential to validate system at different stages. Components were tested against the requirements outlined in Sections \ref{sec: functionalRequirements} and \ref{sec: technicalRequirements}. 

% \bigskip

The following briefly describes the validation methods used for the main requirements:
\begin{itemize}
\item \textbf{Mail Detection:} Various objects ranging from around 20\,g to above 100\,g were weighed on a scale and then placed on the load cell platform to check if the load cell could detect the presence of mail and classify them accurately. 10 different objects were used for testing including letters, pieces of cardboard, and power bank. The setup for this test is shown in Figure \ref{fig: mailDetectionTest}.
%     \item \textbf{Lid Opening Detection:} The tilt switch and LDR were tested by opening and closing the mailbox lid multiple times. Using the serial monitor, the readings from both sensors were observed to ensure they accurately detected the lid status.
%     \item \textbf{LoRa Communication:} The LoRa module was tested by sending test messages from the microcontroller to the LoRaWAN gateway. The successful receipt of messages was confirmed via TTN console and Datacake dashboard.
\item \textbf{Email Notification:} The email notification system was tested by simulating mail detection events and verifying that the mail was detected and emails were sent to the designated recipient. This was tested with the system installed in the mailbox as shown in Figure \ref{fig: finalProduct}. The test was conducted with 3 different objects. For each object, placing inside, removing and opening the lid without placement were tested.
%     \item \textbf{Battery Status Monitoring:} The battery monitor was tested by simulating mail detection events and checking the battery level readings on the dashboard and then checking them against a multimeter.
\item \textbf{Battery Life:} The system was powered by the battery and current consumption was monitored while idle and while sending messages. The readings were used to estimate the battery life. The experimental setup for this test is shown in Figure \ref{fig: currentConsumptionTest}.
\end{itemize}

\begin{figure}[h!]
    \centering
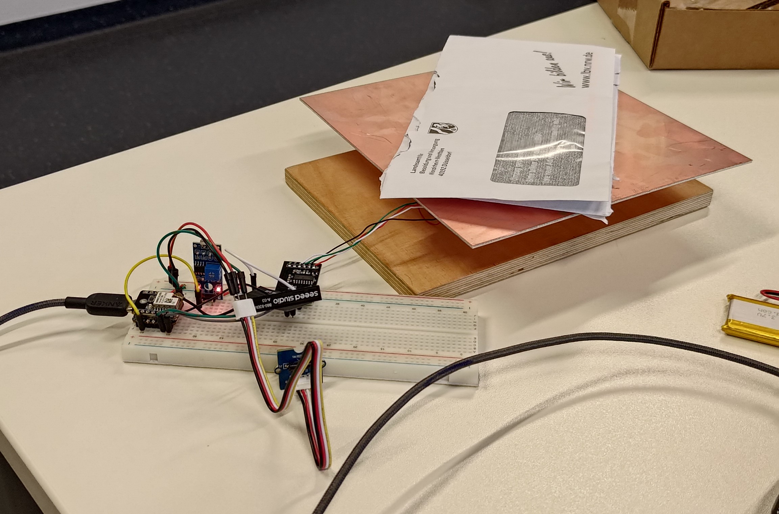
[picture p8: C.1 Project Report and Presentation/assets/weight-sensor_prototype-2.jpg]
    
    \caption{Experimental Setup for Mail Detection Testing Using Various Objects of Different Weights.}
    \label{fig: mailDetectionTest}
\end{figure}

\begin{figure}[H]
    \centering
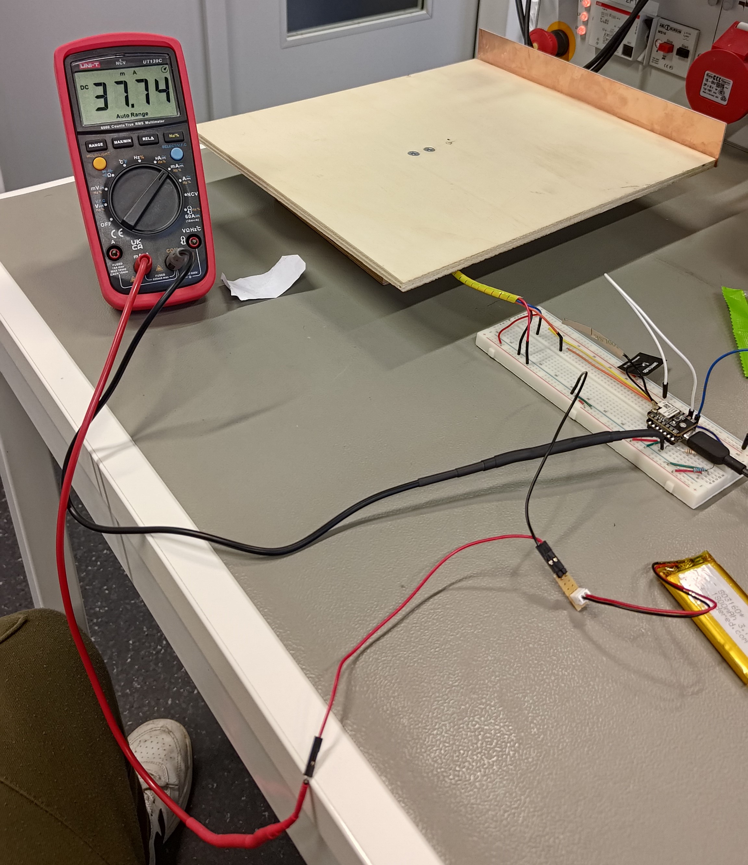
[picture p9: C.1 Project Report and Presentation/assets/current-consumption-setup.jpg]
    
    \caption{Experimental Setup for Battery Life Estimation by Measuring Current Consumption.}
    \label{fig: currentConsumptionTest}
\end{figure}
%%%%%%%%%%%%%%%%%%%%%%%%%%%%%%%%%%%%%%%%%%%%%%%%%%%%%%%%%%%%%%%%%%%%%%%%%%%%%%%%%%%%%%%%%%%%%%%%%%%%%%%%%%%%%%%%%%%%%%%%

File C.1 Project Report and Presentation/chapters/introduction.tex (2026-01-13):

\section{Introduction}
%%%%%%%%%%%%%%%%%%%%%%%%%%%%%%%%%%%%%%%%%%%%%%%%%%%%%%%%%%%%%%%%%%%%%%%%%%%%%%%%%%%%%%%%%%%%%%%%%%%%%%%%%%%%%%%%%%%%%%%%
\subsection{Problem Statement} 
All Professors and Lecturers have a lot to do and may not always have time to check their mailbox. Imagine how long some letters are left in the mailbox for days just because a professor is busy. On the other hand, checking your mailbox only to find nothing is quite frustrating. What if there was a way that your mailbox could tell you when there is mail? What if you had a talking mailbox?

\bigskip

To solve this problem, we introduce \href{https://github.com/AbhinavK02/LoRaProject}{\textbf{The Talking Mailbox}}. The aim of The Talking Mailbox project is to design and assemble a system that can detect the presence of mail within a mailbox in Building~06 and notify the owner of the mailbox.
%%%%%%%%%%%%%%%%%%%%%%%%%%%%%%%%%%%%%%%%%%%%%%%%%%%%%%%%%%%%%%%%%%%%%%%%%%%%%%%%%%%%%%%%%%%%%%%%%%%%%%%%%%%%%%%%%%%%%%%%
\subsection{Literature Review} 
\label{sec: literatureReview}
Before developing The Talking Mailbox, various existing smart mailbox solutions were reviewed, considering their sensor technology and communication methods as well as their advantages and shortcomings. 

\bigskip

Perhaps the simplest solution is presented in \citeA{youtube_mailbox}. A wire connected to the door protrudes out of the box and holds down a flag. Once opened, the flag is released indicating the mailbox has been opened. On the opposite end of the technological spectrum, several commercial smart mailboxes are available. The \citeA{amazon_tuya_sensor} model uses a passive infrared (PIR) motion sensor to detect mail presence, while \citeA{notific_at} employs a motion sensor\footnote{While no literature could be found on the exact technology used, the sensor is likely simple contact switch like a reed switch} attached to the mailbox door. The \citeA{amazon_tuya_sensor} connects directly to Wifi and the \citeA{notific_at} to LoRaWAN, providing remote notifications through dedicated apps. Similar to the \citeA{notific_at}, the \citeA{amazon_instaview} detects door openings utilising a tilt sensor, while the \citeA{bigshopper_xsense} combines a tilt sensor and an IR motion sensor for enhanced detection. Both of these models communicate with a base station within the home via radio frequency (RF) technology, with the \citeA{bigshopper_xsense} capable of managing multiple mailboxes.

\bigskip

While these solutions certainly have merit, The Talking Mailbox offers some advantages over them and has a degree of novelty. While very cheap and reliable, the \citeA{youtube_mailbox} has no means of remote notification. The \citeA{amazon_tuya_sensor} and \citeA{bigshopper_xsense} both use IR sensors which may be prone to false positives from environmental heat sources. The \citeA{amazon_instaview} and \citeA{bigshopper_xsense} require an additional base station device which increases complexity of setup. \project{} eliminates these issues as it connects to LoRaWAN directly and uses multiple sensors (that are not IR-based) to mitigate false positives. Most critically, all of these solutions rely on inferring mail presence from door movement or motion within the box, which may not always be accurate. \project{} directly detects mail presence using a weight sensor, providing a more reliable solution.
%%%%%%%%%%%%%%%%%%%%%%%%%%%%%%%%%%%%%%%%%%%%%%%%%%%%%%%%%%%%%%%%%%%%%%%%%%%%%%%%%%%%%%%%%%%%%%%%%%%%%%%%%%%%%%%%%%%%%%%%
\subsection{Project Plan}
\subsubsection{Schedule} 
The Talking Mailbox project is planned to be executed over a period of 3 months, starting from October 2025 to January 2026. The project is divided into several milestones as shown in Figure \ref{fig: ganttChart}. These deliverables and milestones adhere to the requirements set out in Section \ref{sec: projectRequirements}.
\begin{figure}[H]
    \centering
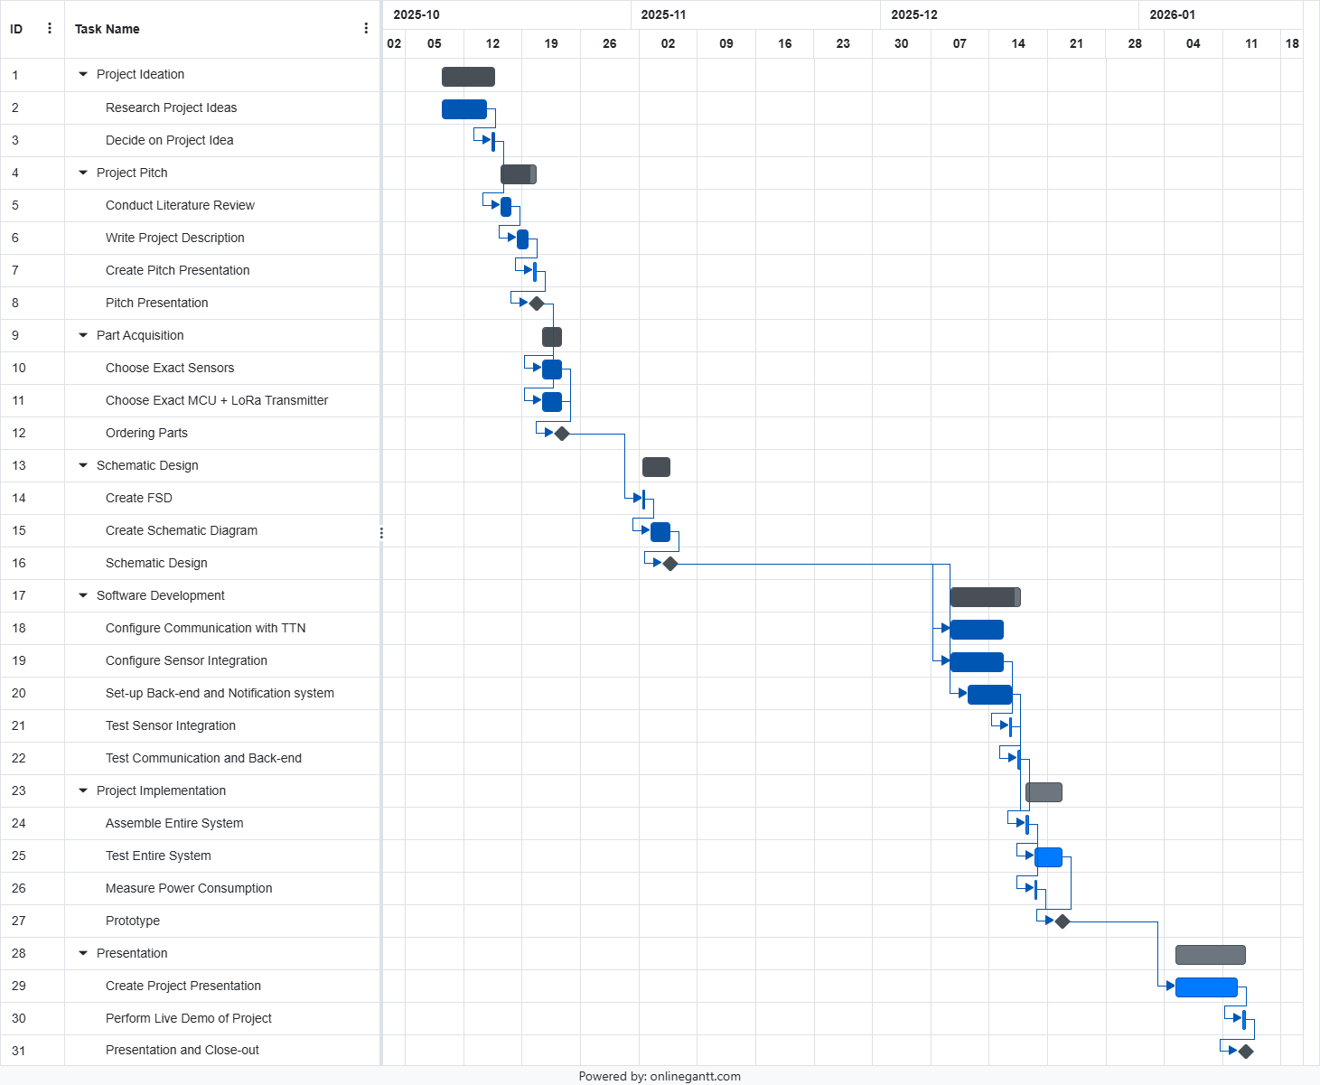
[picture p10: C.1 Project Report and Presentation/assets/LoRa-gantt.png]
    
    \caption{Gantt Chart for The Talking Mailbox Project}
    \label{fig: ganttChart}
\end{figure}

\subsubsection{Resources}
The resources for the project include the budget shown in Section \ref{sec: projectRequirements} and all materials purchased as part of the Bill of Materials in Section \ref{sec: billOfMaterials}. 

\bigskip 

The project team consists of two Mechatronics Engineering Students whose responsibilities are divided as follows:
\begin{itemize}
    \item \textbf{Justin Julius Chin Cheong (34140):} Schematic Design, Sensor integration, Microcontroller programming
    \item \textbf{Abhinav Kothari (33349):} Backend Development, Server Setup and Email Notification System.
    \item \textbf{Both Students:} Component Choice, System Design, System Assembly \& Implementation, System Testing, Report Writing and Presentation Preparation.
\end{itemize}
%%%%%%%%%%%%%%%%%%%%%%%%%%%%%%%%%%%%%%%%%%%%%%%%%%%%%%%%%%%%%%%%%%%%%%%%%%%%%%%%%%%%%%%%%%%%%%%%%%%%%%%%%%%%%%%%%%%%%%%%
\subsection{System Requirements}  
\label{sec: systemRequirements}
\subsubsection{Functional Requirements}
\label{sec: functionalRequirements}
For The Talking Mailbox to be a satisfiable product, the following functional requirements must be implemented:

\begin{itemize}
    \item It can detect if the mailbox is opened.
    \item It can detect light as a redundancy for confirming the opening status of the mailbox.
    \item It can detect whether or not mail is present within the mailbox.
    \item It can communicate if mail is in the box to a website / dashboard (based on LoRaWAN).
    \item It alerts the responsible person via email or dashboard upon mail detection.
    \item It can check the battery status.
    \item It sends battery status updates to a website at regular intervals.
    \item It sends a low battery warning to a website when the battery falls below a defined threshold.
    \item It should run for at least 1 week on a single charge.
\end{itemize}

\subsubsection{Technical Requirements}
\label{sec: technicalRequirements}
For The Talking Mailbox to operate and perform its functions, the following technical requirements must be implemented:

\begin{itemize}
    \item The weight sensor can detect a change in weight of approximately 20\,g. This indicates when a piece of mail has been placed within the box.
    \item The tilt sensor can detect the rotation of the post box lid. This indicates when the lid is opened.
    \item The LDR can detect the change in light intensity by a defined threshold. This indicates when the lid is opened.
    \item The transmitter can reliably connect and communicate via the LoRaWAN Gateway.
    \item The server with which the LoRaWAN communicates can send emails to relevant personnel about the mail.
    \item The power supply is a battery with a working voltage of 3.1\,V to 4.2\,V.
    \item The enclosure can protect the system within a typical indoor environment (IP\,31).
    \item The system should function at temperatures ranging 0--40\textdegree C and humidity 10--90\%.
\end{itemize}

\subsubsection{Project Requirements}
\label{sec: projectRequirements}
For The Talking Mailbox project to produce a functional product upon close out, the following project requirements must be met:

\begin{itemize}
    \item The budget is 100\euro{}.
    \item The project workload is estimated at 100\,h.
    \item The project schedule adheres to the following deadlines:

    \begin{tabular}{@{\hspace{2em}} l r @{}}
        Pitch: & 2025-10-21 \\
        Bill of Materials: & 2025-10-23 \\
        Schematic Design: & 2025-11-23 \\
        Project Implementation: & 2025-12-19 \\
        Project Report: & 2026-01-05 \\
        Project Presentation and Demo: & 2026-01-17
    \end{tabular}
\end{itemize}
%%%%%%%%%%%%%%%%%%%%%%%%%%%%%%%%%%%%%%%%%%%%%%%%%%%%%%%%%%%%%%%%%%%%%%%%%%%%%%%%%%%%%%%%%%%%%%%%%%%%%%%%%%%%%%%%%%%%%%%%

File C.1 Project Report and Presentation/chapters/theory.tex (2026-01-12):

\section{Theoretical Background}
\label{theoreticalBackground}
Before starting with actual project, some theoretical framework is required.
%%%%%%%%%%%%%%%%%%%%%%%%%%%%%%%%%%%%%%%%%%%%%%%%%%%%%%%%%%%%%%%%%%%%%%%%%%%%%%%%%%%%%%%%%%%%%%%%%%%%%%%%%%%%%%%%%%%%%%%%
\subsection{Communication}
\label{sec: communication}
As for the communication, this project used LoRa as the communication encoding and LoRaWAN as the MAC Protocol.
\subsubsection{LoRa}
\label{sec: lora}
\textbf{LoRa} (\textbf{Lo}ng \textbf{Ra}nge) is the physical layer and is a modulation technique which allows for wireless communication. It is able to send information long ranges, with relatively less energy. It is derived from Chirp Spread Spectrum (CSS).
It encodes information similar to how bats/dolphins communicate.
LoRa is used extensively with sensors and actuator projects for the following reasons:
\begin{itemize}
	\item Low power consumption
		\begin{itemize}
			\item Transmitting: ~10 mA
			\item Sleep: ~100 nA
		\end{itemize}
	\item Long range $\rightarrow$ upto ~15 km
	\item Robust against interferences
\end{itemize}
There are many more reasons as well, but these are the primary which were kept in mind for selecting it for this project. \\
LoRa works on a license free frequency range, in Europe this is EU868 (863–870/873 MHz). This will be used in this project (Precisely: 868.1 MHz).
\subsubsection{LoRaWAN}
\label{sec: lorawan}
\textbf{LoRaWAN} (\textbf{LoRa W}ide \textbf{A}rea \textbf{N}etwork) on the other hand is the data link layer on top of LoRa. It defines the communication protocols and architecture.
After the initial release in January 2015, many versions have been released, with latest being 1.0.4 (Series 1.0) and 1.1 (Series 1.1) being released in October 2020 and October 2017 respectively. (Yes, 1.0.4 is newer than 1.1). The version used in this project is 1.0.4.
% , for reasons which will be explained later in Section \ref{sec: issues}.\\ nah ~JC
Figure \ref{fig: LoRaLoRaWAN}, shows how LoRa and LoRaWAN differ and work together.
\begin{figure}[h]
	\centering
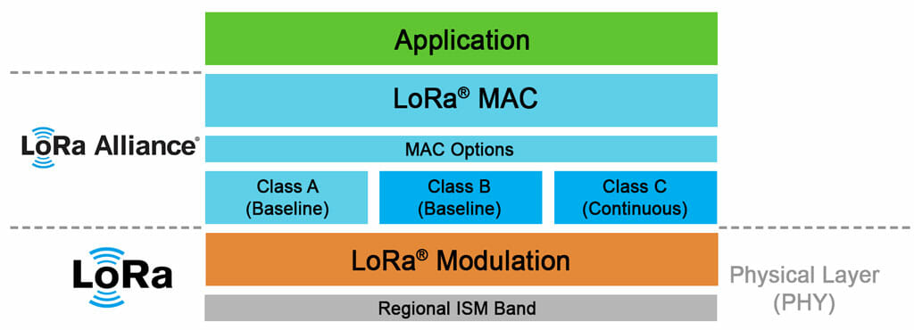
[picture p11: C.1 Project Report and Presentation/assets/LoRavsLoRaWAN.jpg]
		
			\caption{LoRa and LoRaWAN}
			\label{fig: LoRaLoRaWAN}
\end{figure}
%%%%%%%%%%%%%%%%%%%%%%%%%%%%%%%%%%%%%%%%%%%%%%%%%%%%%%%%%%%%%%%%%%%%%%%%%%%%%%%%%%%%%%%%%%%%%%%%%%%%%%%%%%%%%%%%%%%%%%%%
\subsection{Sensors}
\label{sec: sensors}
This project used 3 sensors, their functioning has been briefly described below. This framework is essential to understand the design choices made in this project in Section \ref{sec: systemLayer}.

\subsubsection{Load Cells}
\label{sec: loadCells}
Load Cells are the primary sensor for this project and should be able to detect the presence of mail. Load cells are used to measure force, and hence can achieve this task. The specific load cell used in this project, is a strain gauge load cell. Strain gauges in the cell are arranged in a way that applying force changes resistance of the gauges in arranged in a wheatstone bridge and hence send out a voltage. This voltage is very small, and hence must be amplified. This amplification is done with the HX711 board, which makes it readable for the microcontroller (ESP32-S3). More specific details regarding these equipment can be seen in Section \ref{sec: billOfMaterials}.\\

\subsubsection{Tilt Switch}
\label{sec: tiltSwitch}
Tilt switch is being used to detect the opening of the lid of the postbox. There are multiple types of tilt switches mechanical (rolling ball/ liquid mercury) or electronic (MEMs). The one used in this project \cite{iduinose059} is a mechanical rolling ball switch, due to its lower voltage requirement as well as it being a safer option. The functioning can be demonstrated by Figure \ref{fig: tiltSwitch}. 
\begin{figure}[h]
	\centering
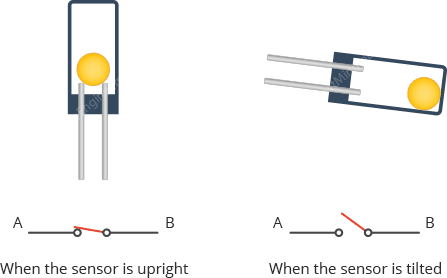
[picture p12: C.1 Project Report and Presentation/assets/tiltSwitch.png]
	
		\caption{Tilt switch working}
		\label{fig: tiltSwitch}
\end{figure}
Whenever the switch is in a specific orientation the ball allows for contact and hence making an electrical connection, else there is no connection.
\subsubsection{LDR}
\label{sec: ldr}
A light dependent resistor is just a resistor which varies its resistance based on the light intensity. This can be detected and hence compared to a threshold to check if the box is open or not.
%%%%%%%%%%%%%%%%%%%%%%%%%%%%%%%%%%%%%%%%%%%%%%%%%%%%%%%%%%%%%%%%%%%%%%%%%%%%%%%%%%%%%%%%%%%%%%%%%%%%%%%%%%%%%%%%%%%%%%%%

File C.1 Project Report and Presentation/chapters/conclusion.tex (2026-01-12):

\section{Conclusion}
%%%%%%%%%%%%%%%%%%%%%%%%%%%%%%%%%%%%%%%%%%%%%%%%%%%%%%%%%%%%%%%%%%%%%%%%%%%%%%%%%%%%%%%%%%%%%%%%%%%%%%%%%%%%%%%%%%%%%%%%
\subsection{Project Summary}
Overall, the results validate the original design objectives of \project{} and demonstrate a clear improvement over existing smart mailbox solutions. By combining direct mail detection, low-power operation, and long-range wireless communication, the project delivers a practical and novel solution to the problem of unattended mailboxes. \project{} not only confirms the feasibility of weight-based mail detection but also establishes a foundation for future enhancements such as multi-mailbox management and tampering alerts.
%%%%%%%%%%%%%%%%%%%%%%%%%%%%%%%%%%%%%%%%%%%%%%%%%%%%%%%%%%%%%%%%%%%%%%%%%%%%%%%%%%%%%%%%%%%%%%%%%%%%%%%%%%%%%%%%%%%%%%%%
\subsection{Future Work / Improvements}
While working on The Talking Mailbox project, several areas for potential improvements were identified 
that could enhance the functionality, reliability, and user experience of the system. These improvements 
include:
\begin{itemize}
    \item \textbf{Better lid opening detection}: While the LDR and tilt sensor provide good and reliable detection of the lid opening, they can be replaced with a single reed switch. This would reduce complexity and power consumption.
    \item \textbf{Improved housing}: Housing of the components can be combined with load cell platform for a better fit and protection of the components.
    \item \textbf{Additional information}: A camera can be added to capture images of the mail inside the box. This would provide visual confirmation of mail presence and enhance user experience. An LED can be used in conjunction with the camera to provide illumination inside the mailbox even when closed.
    \item \textbf{Easier server access}: The server can be deployed on a local raspberry pi or similar device to allow for local access and control. This would eliminate the need for an external hosting service and provide more flexibility.
    \item \textbf{Tampering alert}: A buzzer can be added to sound an alarm when tampering is detected. This would enhance security.
    \item \textbf{Improved Battery Life}: Implementing low power design could improve battery life. This may include using a custom PCB with minimal components instead of development boards or integrating more low power components.
    \item \textbf{Energy harvesting}: A piezo-element can also be added to the lid to harvest energy from the opening and closing of the mailbox. This would extend battery life and reduce maintenance.
    \item \textbf{Expansion to multiple mailboxes}: The system can be expanded to support multiple mailboxes, serving multiple users from a single controller. With the existing device ID set-up in the code, this can be achieved simply by connecting multiple sensor configs to the MCU using multiplexers and expanding the payload by prefixing the unique device ID before the sensor data.
\end{itemize}
%%%%%%%%%%%%%%%%%%%%%%%%%%%%%%%%%%%%%%%%%%%%%%%%%%%%%%%%%%%%%%%%%%%%%%%%%%%%%%%%%%%%%%%%%%%%%%%%%%%%%%%%%%%%%%%%%%%%%%%%

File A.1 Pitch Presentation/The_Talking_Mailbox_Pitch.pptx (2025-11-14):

## The Talking Mailbox

LoRa-Enabled Post Detection System

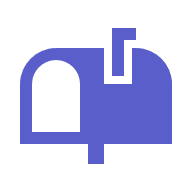
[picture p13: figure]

By Abhinav Kothari (33349) and Justin Chin Cheong (34140)

## Problem

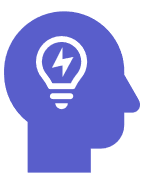
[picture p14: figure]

Professors/Instructors have a lot to do, and don’t always have the time to see the mailbox
Checking for mailbox and finding nothing can be annoying and a waste of time
Posts can remain unchecked for a long time if professor is busy
No way of knowing if post received if away (e.g., on conference/vacation)

## Solution: The Talking Mailbox

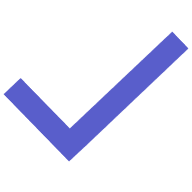
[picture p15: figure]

Check post

Your mailbox knows when something arrives
- Weight sensor to detect post in box
- Same sensor can detect when post is removed

Notify

The mailbox talks to you
- Update a website to see if post is in the box
- Optional: mail the respective person

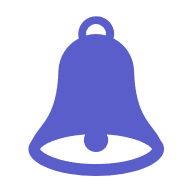
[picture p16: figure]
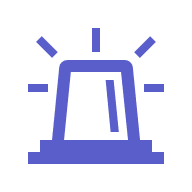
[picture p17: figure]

Alert

Stay alert
- Monitors battery and alerts user in case of low battery
- Detects opening, and alerts user: avoid tampering

## Approach to Solution

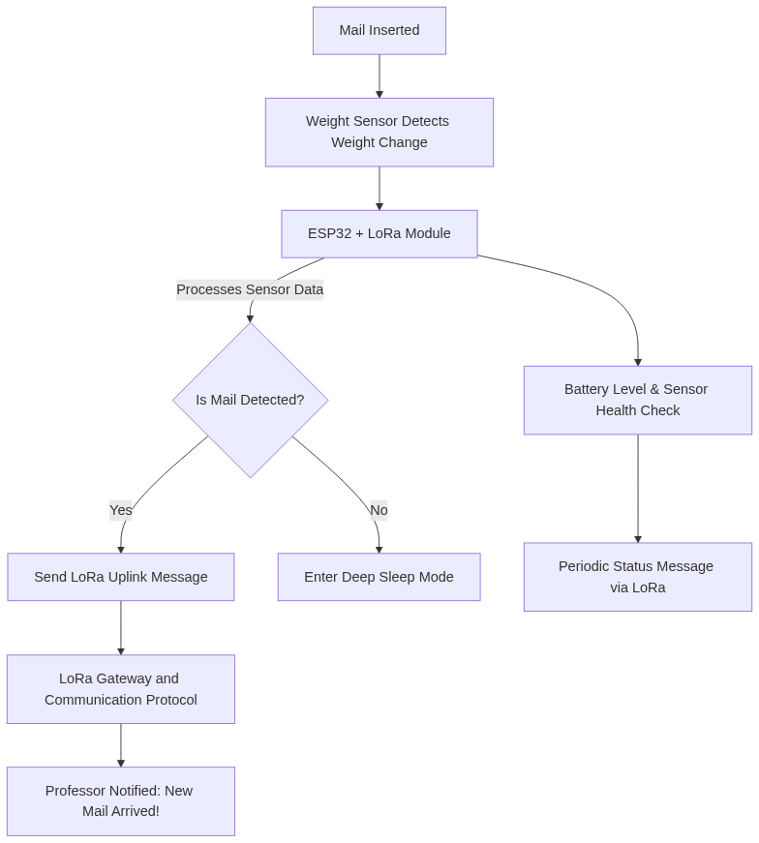
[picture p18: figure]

Check for post

Use a weight sensor to detect if a post comes in

Detect
opening

A combination of Light Dependent Resistor and Tilt Sensor on the lid to detect opening

Notify personnel

Detecting post triggers LoRaWAN gateway notification (website/mail)

Monitor
battery

Check voltage levels, in case it drops below a threshold, alert the user

## Product technologies and interaction

Weight
Sensor

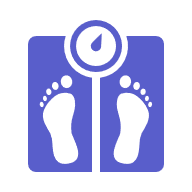
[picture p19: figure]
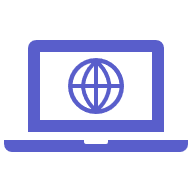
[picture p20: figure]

Website/Mail

Backend Layer

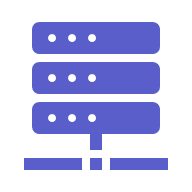
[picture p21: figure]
Server with solid fill

LDR

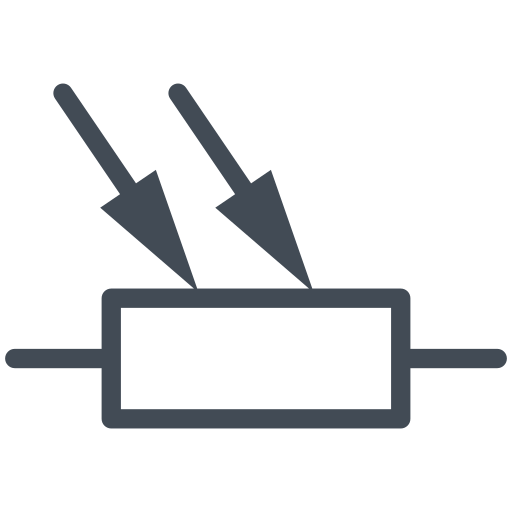
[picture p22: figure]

WiFi LoRa ESP32

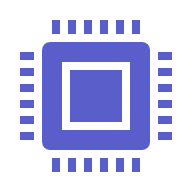
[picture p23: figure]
Processor with solid fill

LoRa Antenna

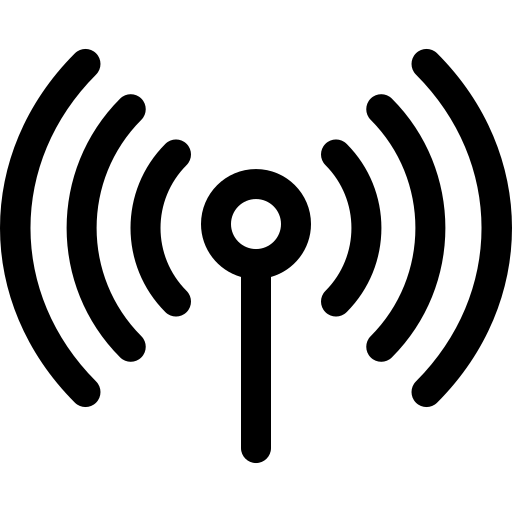
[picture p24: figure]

Tilt Sensor


Legend Communication
Wired
LoRaWAN
Internal server

## Thank You

Any questions?

## Functional Requirements

For The Talking Door to be a satisfiable product, the following functional requirements must be implemented:
- It can detect whether or not mail is present within the mailbox
- It can detect if the mailbox is opened
- It can check the battery status
- It can communicate if a mail is in the box to a website (based on LoRaWAN)
- It can detect light as a redundancy for confirming the opening status of the mailbox
- It alerts the responsible person via email or dashboard upon mail detection
- It sends battery status updates to a website every hour
- It sends a low battery warning to a website when the battery falls below a defined threshold

## Technical Requirements

For The Talking Door to operate and perform its functions, the following technical requirements must be implemented:
- The weight sensor can detect a change in weight of approximately 20g. This indicates when a piece of mail has been placed within the box
- The tilt sensor can detect the rotation of the post box lid. This indicates when the lid is opened.
- The LDR can detect the change in light intensity by a defined threshold. This indicates when the lid is opened.
- The transmitter can reliably connect and communicate via the LoRaWAN Gateway.
- The server with which the LoRaWAN communicates, can send emails to relevant personnel about the mail.
- The power supply is a battery with a working voltage of 3.1V to 5.5V
- The enclosure can protect the system within a typical indoor environment (IP 31)
- The system should function at temperatures ranging 0-40°C and humidity 10-90%

## Price Estimates

Component | Price Estimate [EUR]
Weight Sensor | 8.00
Digital Tilt Sensor | 3.00
ESP 32 + LoRa Module + Antenna | 15.00
LDR | 1.00
Battery | 9.00
Housing estimate (extreme case) | 20.00
Total | 55

## Attribution Links

Some icons were used from flaticons, here are the attribution links:
- https://www.flaticon.com/free-icons/light-dependent-resistor : Light dependent resistor icons created by verluk – (https://www.flaticon.com/free-icons/antenna) Flaticon
- https://www.flaticon.com/free-icons/antenna : Antenna icons created by Freepik – Flaticon
- https://www.flaticon.com/free-icons/spirit-level : Spirit level icons created by juicy_fish - Flaticon

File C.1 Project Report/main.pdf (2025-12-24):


# The Talking Mailbox

## 2907 Sensors and Actuator Networks

## Winter Semester 2025/26

## Authors:

Justin Julius Chin Cheong | Abhinav Kothari
34140 | 33349
MSE | MSE

## Contents

1 Introduction | 1
2 Theoretical Background | 2
3 Methodology and Design | 4
4 Results and Implementation | 6
5 Discussion | 7
6 Conclusion | 7

## 1 Introduction

### 1.1 Problem Statement

All Professors and Lecturers have a lot to do and may not always have time to check their mailbox. Imagine how long some letters are left in the mailbox for days just because a professor is busy. On the other hand, checking your mailbox only to find nothing is quite frustrating. What if there was a way that your mailbox could tell you when there is mail? What if you had a talking mailbox?
To solve this problem, we introduce The Talking Mailbox. The aim of The Talking Mailbox project is to design and assemble a system that can detect the presence of mail within a mailbox in Building 06 and notify the owner of the mailbox.

### 1.2 Literature Review

### 1.3 Project Plan

### 1.4 System Concept

### 1.4.1 Functional Requirements

For The Talking Door to be a satisfiable product, the following functional requirements must be implemented:

It can detect if the mailbox is opened.

It can detect light as a redundancy for confirming the opening status of the mailbox.

It can detect whether or not mail is present within the mailbox.

It can communicate if mail is in the box to a website / dashboard (based on LoRaWAN).

It alerts the responsible person via email or dashboard upon mail detection.

It can check the battery status.

It sends battery status updates to a website at regular intervals.

It sends a low battery warning to a website when the battery falls below a defined threshold.

### 1.4.2 Technical Requirements

For The Talking Door to operate and perform its functions, the following technical requirements must be implemented:

The weight sensor can detect a change in weight of approximately 20 g. This indicates when a piece of mail has been placed within the box.

The tilt sensor can detect the rotation of the post box lid. This indicates when the lid is opened.

The LDR can detect the change in light intensity by a defined threshold. This indicates when the lid is opened.

The transmitter can reliably connect and communicate via the LoRaWAN Gateway.

The server with which the LoRaWAN communicates can send emails to relevant personnel about the mail.

The power supply is a battery with a working voltage of 3.1 V to 5.5 V.

The enclosure can protect the system within a typical indoor environment (IP 31).

The system should function at temperatures ranging 0–40°C and humidity 10–90%.

Justin Julius Chin Cheong 34140 Abhinav Kothari 33349

### 1.4.3 Project Requirements

For The Talking Mailbox project to produce a functional product upon close out, the following project requirements must be met:

The budget is 100e.

The project workload is estimated at 100 h.

The project schedule adheres to the following deadlines:

Pitch: | 2025-10-21
Bill of Materials: | 2025-10-23
Schematic Design: | 2025-11-23
Project Implementation: | 2025-12-19
Project Report: | 2026-01-05
Project Presentation and Demo: | 2026-01-17

## 2 Theoretical Background

Before starting with actual project, some theoretical framework is required.

### 2.1 Communication

As for the communication, this project used LoRa as the communication encoding and LoRaWAN as the MAC Protocol.

### 2.1.1 LoRa

LoRa (Long Range) is the physical layer and is a modulation technique which allows for wireless communication. It is able to send information long ranges, with relatively less energy. It is derived from Chirp Spread Spectrum (CSS). It encodes information similar to how bats/dolphins communicate. LoRa is used extensively with sensors and actuator projects for the following reasons:

Low power consumption

– Transmitting: 10 mA

– Sleep: 100 nA

Long range → upto 15 km

Robust against interferences

There are many more reasons as well, but these are the primary which were kept in mind for selecting it for this project.
LoRa works on a license free frequency range, in Europe this is EU868 (863–870/873 MHz). This will be used in this project (Precisely: 868.1 MHz).

### 2.1.2 LoRaWAN

LoRaWAN (LoRa Wide Area Network) on the other hand is the data link layer on top of LoRa. It defines the communication protocols and architecture. After the initial release in January 2015, many versions have been released, with latest being 1.0.4 (Series 1.0) and 1.1 (Series 1.1) being released in October 2020 and October 2017 respectively. (Yes, 1.0.4 is newer than 1.1). The version used in this project is 1.0.4, for reasons which will be explained later in Section 4.1.2.
Figure 1, shows how LoRa and LoRaWAN differ and work together.

### 2.2 Sensors

This project used 3 sensors, their functioning has been briefly described below. This framework is essential to understand the design choices made in this project in Section 3.2.


Figure 1: LoRa and LoRaWAN

### 2.2.1 Load Cells

Load Cells are the primary sensor for this project and should be able to detect the presence of mail. Load cells are used to measure force, and hence can achieve this task. The specific load cell used in this project, is a strain gauge load cell. Strain gauges in the cell are arranged in a way that applying force changes resistance of the gauges in arranged in a wheatstone bridge and hence send out a voltage. This voltage is very small, and hence must be amplified. This amplification is done with the HX711 board, which makes it readable for the microcontroller (ESP32-S3). More specific details regarding these equipment can be seen in Section 3.2.4.

### 2.2.2 Tilt Switch

Tilt switch is being used to detect the opening of the lid of the postbox. There are multiple types of tilt switches mechanical (rolling ball/ liquid mercury) or electronic (MEMs). The one used in this project is a mechanical rolling ball switch, due to its lower voltage requirement as well as it being a safer option. The functioning can be demonstrated by Figure 2. Whenever the switch is in a specific orientation the

Figure 2: Tilt switch working


ball allows for contact and hence making an electrical connection, else there is no connection.

### 2.2.3 LDR

A light dependent resistor is just a resistor which varies its resistance based on the light intensity. This can be detected and hence compared to a threshold to check if the box is open or not.


Figure 3: Functional structure diagram of the system architecture

## 3 Methodology and Design

### 3.1 Design Approach

### 3.2 System Design

### 3.2.1 System Architecture

### 3.2.2 Schematic Design

3.2.3 3D Design

As understood from Section 2.2.1, to reliably detect any weight, the load cell must be allowed to bent as easily as possible. To prevent any mail from ”‘missing”’ the detection platform, the platform must cover the entire box area. The design which allows us to do this is shown in Figure 4.


(a) 3D Model of Load Cell Arrangement | (b) Platform for mail detection

Figure 4: 3D Model of detection platform

The height with the hex nuts, allow the load cell to have clearance to bend during load from the upper platform. The off center screw platform on both platform allow for best readings from the load cell.

The size of the upper platform should match the post box size, however the lower platform allows for flexibility, it can be made just large enough to not cause toppling over and allow us to place necessary modules (such as the HX711).
Some other design considerations include the requirement of the platform being rigid and lightweight, to allow load cell to be as sensitive as possible. A good material to use for the platform is wood. The screws should also be flat with the platform, to prevent mail from tearing / getting stuck. Keeping all these design considerations in mind, the following final product can be seen in Figure 5.


Figure 5: Final product inside the post box

### 3.2.4 Bill of Materials

This is an estimate of the materials required to make this project, these are all over estimates, as all components/materials except 2.1 - 2.6 were used from the university stock.

Item | Part | Description | Qty | Notes | Price (¿)

### 1.0 Mechanical Components

1.1 | Top Plate | Detection Plate | 1 | Wood (40x30x0.5cm) | 5.00
1.2 | Bottom Plate | Base for load cell | 1 | Wood (15x15x0.5cm) | 3.00
1.3 | M4 Screw | Top plate screw | 2 | - | 1.00
1.4 | M4 Hex Nut | Height spacer nut | 4 | - | 0.50
1.5 | M5 Screw | Bottom plate screw | 2 | - | 1.00
1.6 | M4 Hex Nut | Height spacer nut | 4 | - | 0.50

### 2.0 Electrical Components

2.1 | Load Cell + HX711 | Load cell + Amplifier module | 1 | JOY-IT | 6.40
2.2 | Tilt Switch | Ball tilt switch | 1 | IDUINO | 0.94
2.3 | LDR | Light resistor | 1 | SERTRONICS | 1.35
2.4 | Battery | 1800 mAh Li-Ion | 1 | SOLDERED | 10.24
2.5 | MCU + LoRa | Xiao ESP32 + SX1262 | 1 | Seeedstudio | 11.68
2.6 | Antenna | Longer antenna | 1 | Amphenol-SAA | 2.69
2.7 | – kOhm resistor | Through Hole | 1 | YAGEO | 0.10
2.8 | – kOhm resistor | Through Hole | 1 | YAGEO | 0.10
2.9 | Wires | Jumper wires of different length | - | - | 0.30
Tax (VAT 20%) | | | | | 8.96
Grand Total (¿) | | | | | 53.76

Table 1: Combined Mechanical and Electrical Bill of Materials with Total Cost

### 3.3 Validation Method

## 4 Results and Implementation

### 4.1 Implementation

### 4.1.1 Backend Implementation - Application Layer

The LoRaWAN is able to send the bits to The Things Network. However for these to be actually useful to the user they must be decoded and used to represent relevant information for a user, this includes the mail status, the battery and which post box it is. For this first a payload decoder must be made. This is made keeping in mind how bits were encoded in the first place. The decoder can be seen in Code 1

1 | function Decoder ( payload , port ) {
2 | if ( payload . length < 4) {
3 | return [
4 | { field : " ERROR ", value : " Payload too short or empty " } ,
5 | { field : " RAW_HEX ", value : payload .map( function ( b ) { return ("0" + b . toString (16) ) . slice ( -2) }) . join ("") }
6 | ];
7 | }

8
9 | var id = payload [0];
10 | id = parseInt ( id . toString (16) ) ;
11 | var stateByte = payload [1];
12 | var valueID = payload [2];
13 | var val = payload [3];
14 | var statusText = " Unknown ";
15 | var valueType = " Unknown ";

16
17 | if ( stateByte === 0 x04 ) statusText = " Tampering Alert ";
18 | else if ( stateByte === 0 x05 ) statusText = " Heavy Mail ";
19 | else if ( stateByte === 0 x06 ) statusText = " Medium Mail ";
20 | else if ( stateByte === 0 x07 ) statusText = " Light Mail ";
21 | else if ( stateByte === 0 x08 ) statusText = "No Mail ";

22
23 | if( valueID === 0 x09 ) valueType = " BATTERY ";

24
25 | if ( id === 0 x33 ) box = "SAN Postbox ";
26 | else box = " Unknown box ";

27
28 | return [
29 | { field : " DEVICE_ID ", value : id } ,
30 | { field : " STATE_CODE ", value : stateByte } ,
31 | { field : " STATUS_MESSAGE ", value : statusText } ,
32 | { field : " BOX_NAME ", value : box } ,
33 | { field : valueType , value : val }
34 | ];
35 | }
| Listing 1: Payload Decoder Function for LoRaWAN

### 4.1.2 Issues

### 4.2 Validation Results

## 5 Discussion

### 5.1 Product Evaluation

### 5.2 Potential Improvements

## 6 Conclusion

### 6.1 Project Summary

### 6.2 Future Work

## Appendix

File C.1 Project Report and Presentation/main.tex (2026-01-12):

\documentclass[12pt,a4paper]{report}
\usepackage{labreport}

% -------------------------------- Variables ---------------------------------
\renewcommand{\authA}{Justin Julius Chin Cheong}
\renewcommand{\authB}{Abhinav Kothari}
\renewcommand{\matnumA}{34140}
\renewcommand{\matnumB}{33349}
\renewcommand{\project}{The Talking Mailbox}
% \addbibresource{ref.bib} % Bibliography file
% --------------------------- Container Templates -----------------------------
% Figure
% \begin{figure}[h!]
%     \centering
%     \includegraphics[width=0.8\textwidth]{smth.png}
%     \caption{brief desc.}
%     \label{fig:smth}
% \end{figure}

% Code
% \begin{lstlisting}[language=C, caption={brief desc.}, label={code:smth}]
% // Code here
% \end{lstlisting}

% Table
% \begin{table}[h!]
%     \centering
%     \begin{tabular}{|c|c|c|}
%         \hline
%         Input 1 & Input 2 & Output \\ \hline
%         0 & 0 & 0 \\ \hline
%         0 & 1 & 1 \\ \hline
%         1 & 0 & 1 \\ \hline
%         1 & 1 & 0 \\ \hline
%     \end{tabular}
%     \caption{desc}
%     \label{tab:smth}
% \end{table}

% \section*{Task :}
% \subsection*{Specifications}
% \subsection*{Circuitry and Logic}
% \subsection*{Function and Results}

%--------------------------------------------------------
%------------Title Section-------------------------------
%--------------------------------------------------------
\begin{document}

% Title
\begin{titlepage}
    \thispagestyle{empty}
    % logo
    \begin{flushright}
        
    \end{flushright}
    
    % title
    \centering
    \vspace{1cm}
    {\Huge \textbf{\project} \par}
    \vspace{1.5cm}
    {\Large 2907 Sensors and Actuator Networks \par}
    \vspace{1 cm}
    {\Large Winter Semester 2025/26 \par}
    \vspace{1.5 cm}

    \vspace{2 cm}

    % author info
    {\Large \textbf{Authors:}}

    \vspace{1 em}

    \begin{tabular}{c c}
    \href{https://jcchincheong-bb.github.io/}{\authA} & \href{https://www.linkedin.com/in/abhinav-kothari-2ak/}{\authB} \\
    \matnumA & \matnumB \\
    MSE & MSE \\
    \end{tabular}
\end{titlepage}

% TOC
\thispagestyle{empty}
\tableofcontents
\thispagestyle{empty}
\clearpage

%-------------------------------------------------------------------------
%-----------------Main Content--------------------------------------------
%------------------------------------------------------------------------
\pagenumbering{arabic}   % Page number = 1 starts here

%----------------------------------------------------------------------------------------------------------------------
\input{chapters/introduction}
\pagebreak
%----------------------------------------------------------------------------------------------------------------------
\input{chapters/theory}
\pagebreak
%----------------------------------------------------------------------------------------------------------------------
\input{chapters/design}
\pagebreak
%----------------------------------------------------------------------------------------------------------------------
\input{chapters/results}
\pagebreak
%----------------------------------------------------------------------------------------------------------------------
\input{chapters/discussion}
\pagebreak
%----------------------------------------------------------------------------------------------------------------------
\input{chapters/conclusion}
\pagebreak
%----------------------------------------------------------------------------------------------------------------------
\input{chapters/acknowledgement}
\bibliographystyle{apacite}
\bibliography{ref}
%----------------------------------------------------------------------------------------------------------------------
% \pagebreak
% \appendix
% \section*{Appendix}
% -----------------------------------------------------------

\end{document}

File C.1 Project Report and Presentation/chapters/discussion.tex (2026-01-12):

\section{Discussion}
\label{sec: discussion}
%%%%%%%%%%%%%%%%%%%%%%%%%%%%%%%%%%%%%%%%%%%%%%%%%%%%%%%%%%%%%%%%%%%%%%%%%%%%%%%%%%%%%%%%%%%%%%%%%%%%%%%%%%%%%%%%%%%%%%%%
As demonstrated in Section~\ref{sec: completeSystem}, \project{} successfully fulfils all functional and technical requirements defined in Section~\ref{sec: systemRequirements}. The completed system reliably detects mailbox opening events, determines the presence of mail, categorize the current amount of mail into weight class, and communicates this information remotely via LoRaWAN. The results confirm that the proposed design is both technically feasible and effective within the intended indoor deployment environment.

\bigskip

A key outcome of this project is the system’s ability to detect the current state of the mailbox rather than merely inferring activity. Unlike many of the smart mailbox solutions discussed in \ref{sec: literatureReview} that rely solely on door movement or motion detection, \project{} directly measures mail presence using a load cell. This enables the system to distinguish between meaningful events (mail added or removed) and non-meaningful events (lid opened without delivery), thereby reducing false notifications. The use of the tilt switch and light-dependent resistor in addition to load cell also proved effective in increasing system robustness. It essentially uses the same door motion logic as the \citeA{amazon_instaview}, \citeA{bigshopper_xsense} and \citeA{notific_at} along with a LDR as a redundancy. This makes the system even more reliable in detection. 

\bigskip

Another significant distinction is the system’s communication architecture. While the \citeA{amazon_instaview} and \citeA{bigshopper_xsense}, require base stations that connect to the internet for them, \project{} connects directly to LoRaWAN infrastructure. This reduces installation complexity and allows for simple communication deployment without additional hardware in the user’s home or office. However, this LoRaWAN communication protocol requires existing gateways to exist in the user's area; a short-coming the \citeA{notific_at} also faces. Only the \citeA{amazon_tuya_sensor} which connects directly to Wifi over come this issue of additional infrastructure as it can be assumed that most users have Wifi already. 

\bigskip

Despite its successful operation, the system does present some limitations. The load cell and HX711 sensor requires calibration for each installation as each platform constructed maybe have slight differences in weight and orientation. This of course increases the installation complexity. The load cell may also experience long term drift and may require maintenance. The aforementioned LoRaWAN communication has the issue of relying on existing infrastructure which is dependent on the area. Users can certainly install a LoRaWAN gateway themselves, however this renders the communication solution no better than existing products. Finally, the current backend implementation requires a continuously running server, which introduces deployment complexity for non-technical users. This however is easily fixed as the employment of a Datacake dashboard handles all of the hosting and just presents the user with an aesthetic user interface.

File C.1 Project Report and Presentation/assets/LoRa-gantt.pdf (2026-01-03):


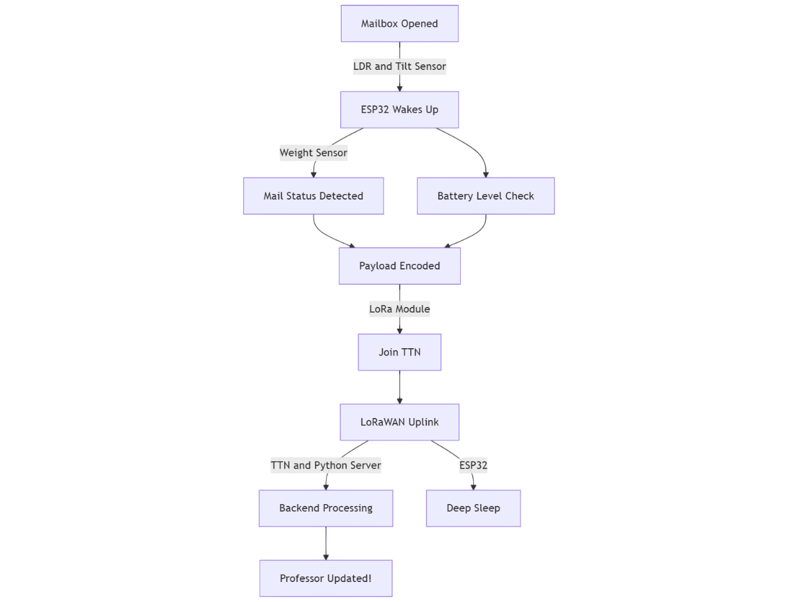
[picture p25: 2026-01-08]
C.1 Project Report and Presentation/assets/system-flowchart-transparent.png

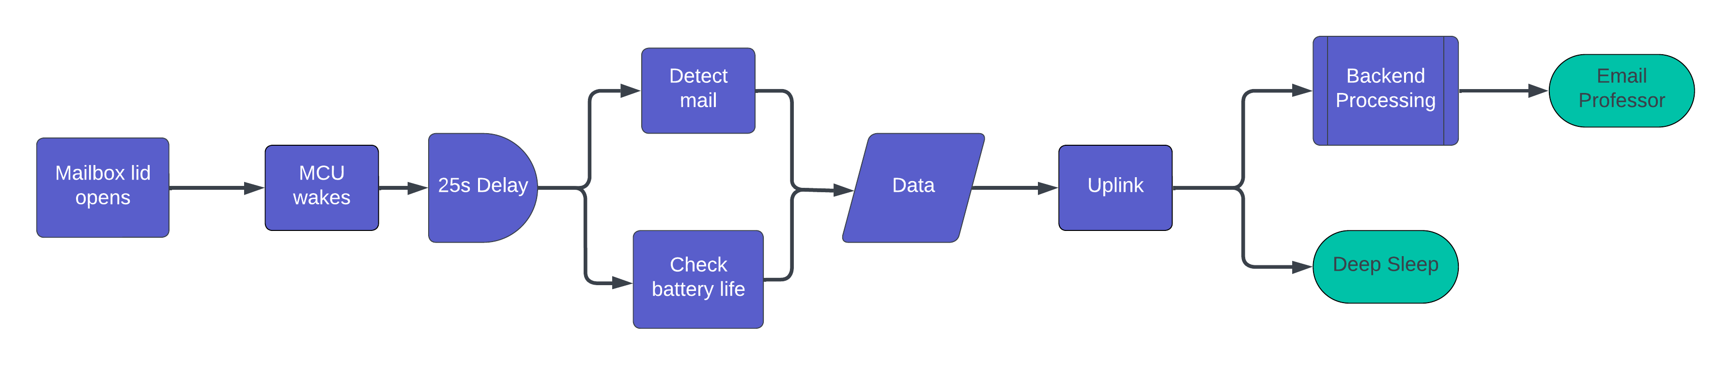
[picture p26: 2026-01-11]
C.1 Project Report and Presentation/assets/system-flowchart_hor-transparent_v2.png

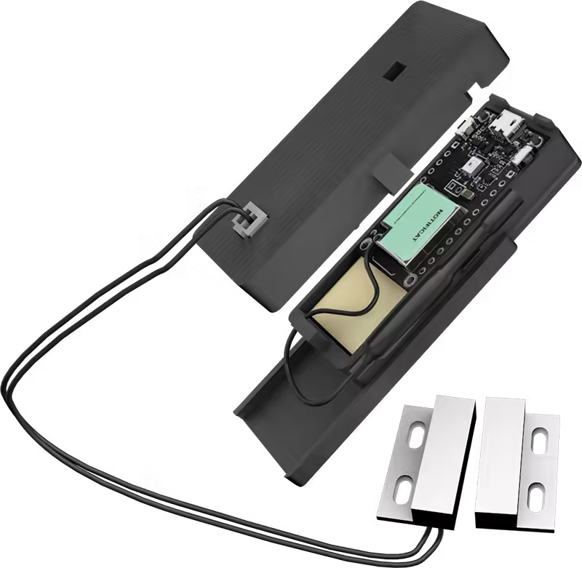
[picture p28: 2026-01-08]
C.1 Project Report and Presentation/assets/notific-at.png

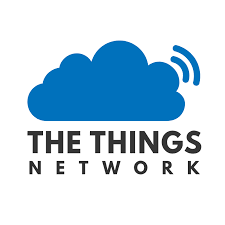
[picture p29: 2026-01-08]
C.1 Project Report and Presentation/assets/TTN.png

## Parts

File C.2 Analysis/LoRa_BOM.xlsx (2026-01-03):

Item | Part | Description | Qty | Notes | Price (€)
1.1 | Top Plate | Detection Plate | 1 | Wood (40x30x0.5cm) | 5
1.2 | Bottom Plate | Base for load cell | 1 | Wood (15x15x0.5cm) | 3
1.3 | M4 Screw | Top plate screw | 2 | - | 1
1.4 | M5 Hex Nut | Height spacer nut | 4 | - | 0.5
1.5 | M5 Screw | Bottom plate screw | 2 | - | 1
1.6 | M6 Hex Nut | Height spacer nut | 4 | - | 0.5
1.7 | Misc. | Tape, Glue | - | - | 0.5
2.1 | Load Cell + HX711 | Load cell + Amplifier module | 1 | JOY-IT | 6.4
2.2 | Tilt Switch | Ball tilt switch | 1 | IDUINO | 0.94
2.3 | LDR | Light resistor | 1 | SERTRONICS | 1.35
2.4 | Battery | 1800 mAh Li-Ion | 1 | SOLDERED | 10.24
2.5 | MCU + LoRa | Xiao ESP32 + SX1262 | 1 | Seeedstudio | 11.68
2.6 | Antenna | Long range antenna | 1 | Amphenol-SAA | 2.69
2.7 | 1 kOhm resistor | Through Hole | 1 | YAGEO | 0.1
2.8 | 2 kOhm resistor | Through Hole | 1 | YAGEO | 0.1
2.9 | Wires | Jumper wires of different length | - | - | 0.3
2.1 | Misc. | Breadboard, Wire Sleeves, Solder | - | - | 0.5
 | Tax (VAT 20%) |  |  |  | 9.16
 | Grand Total (€) |  |  |  | 54.96

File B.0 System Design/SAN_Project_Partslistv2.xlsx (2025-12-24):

Group no. |  | 99 |  |  |  | Project | The Talking Mail Box
Date |  | 23.10.2025 |  |  |  | Team members | Justin Chin Cheong, Abhinav Kothari
No. | Qty. | manufacturer | component | ordering code (manufacturer) | vendor | ordering code (vendor) | Price per unit €* | Price €* | Link
1 | 1 | IDUINO | Tilt Sensor | SE059 | Reichelt | DEBO1 TILT | 0.94 | 0.94 | https://www.reichelt.com/de/en/shop/product/developer_boards_-_tilt_switch_digital-282564
2 | 1 | SERTRONICS | Light Dependent Resistor Developer board | LIGHT-SENSOR | Reichelt | DEBO LIGHT SENS | 1.35 | 1.35 | https://www.reichelt.com/de/en/shop/product/developer_boards_-_light_sensor_with_high_low_output_lm393-224222
3 | 1 | Seeedstudio | Xiao ESP32-S3 + Wio-SX1262 | 102010611 | Other | SEE-25675 | 11.68 | 11.68 | https://botland.store/lora-lorawan/25675-xiao-esp32-s3-wio-sx1262-kit-for-meshtastic-and-loralorawan-seeedstudio-102010611-4897068320128.html
4 | 1 | SOLDERED | Li-Ion Akku | 333284 | Reichelt | AKKU SOLD333284 | 8.57 | 8.57 | https://www.reichelt.de/de/de/shop/produkt/li-ion_akku_soldered_333284_1800_mah_3_7_v-373548
5 | 1 | Joy-It | Arduino Pressure Sensor 20g to 10 kg | SEN-PRESSURE10 | Reichelt | ARD SEN PRESSURE | 5.15 | 5.15 | https://www.reichelt.com/de/en/shop/product/arduino_-_pressure_sensor_20_g_to_10_kg-284398
6 | 1 | DFRobot | RP-L-170 Thin Pressure Sensor | SEN0295 | Mouser | 426-SEN0295 | 5.59 | 5.59 | https://www.mouser.de/ProductDetail/DFRobot/SEN0295
7 | 2 | Adafruit | Alpha MF02A-N-221-A01 FSR | 1075 | Mouser | 485-1075 | 6.66 | 13.32 | https://www.mouser.de/ProductDetail/Adafruit/1075?qs=GURawfaeGuDaOmXus2Zwlg%3D%3D
8 | 1 | Microchip | MCP6002 I/P Operationsverstärker Dual 1.8V 1MHz | MCP6002 | HSRW | 1715 | 0.41 | 0.41 | https://www.mouser.de/ProductDetail/Microchip-Technology/MCP6002-I-P?qs=sGAEpiMZZMsxiS4eJwGuBtZupmX4AUSq
9 | 2 | Joy-It | Load cell + amplifier | SEN-HX711-01 | Reichelt | DEBO HX711-01 | 6.40 | 12.80 | https://www.reichelt.com/de/en/shop/product/developer_boards_-_a_d_converter_-_balance-316296
10 | 1 | Amphenol-SAA | PIOV008NRAA-100 | PIOV008NRAA-100 | Mouser | 523-PIOV008NRAA-100 | 2.69 | 2.69 | Lo (https://www.mouser.de/ProductDetail/Amphenol-SAA/PIOV008NRAA-100?qs=GedFDFLaBXFCaCiGvxFhnA%3D%3D)
11 |  |  |  |  |  |  |  | 0.00
12 |  |  |  |  |  |  |  | 0.00
13 |  |  |  |  |  |  |  | 0.00
14 |  |  |  |  |  |  |  | 0.00
15 |  |  |  |  |  |  |  | 0.00
 |  |  |  |  |  | total price* |  | 62.50
List of suitable vendors: |  |  |  |  |  | value added tax (VAT) |  | 11.88
shop |  | language | homepage |  |  | total price inclusive VAT: |  | 74.38
HSRW |  | en | https://ee.hsrw.org/
Mouser |  | en/de | https://www.mouser.de/
Reichelt |  | en/de | https://www.reichelt.de/ |  |  |  | *without value added tax (VAT)
Conrad |  | en/de | https://www.conrad.biz/
Other |  |  | only when absolutely necessary
Botland |  | en/de | https://botland.store/

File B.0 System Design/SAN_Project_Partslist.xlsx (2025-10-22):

Group no. |  | 99 |  |  |  | Project | The Talking Mail Box
Date |  | 23.10.2025 |  |  |  | Team members | Justin Chin Cheong, Abhinav Kothari
No. | Qty. | manufacturer | component | ordering code (manufacturer) | vendor | ordering code (vendor) | Price per unit €* | Price €* | Link
1 | 1 | OncQue | Tilt Sensor | RBS311104 | Mouser | 108-RBS311104 | 3.00 | 3.00 | https://www.mouser.de/ProductDetail/OncQue/RBS311104?qs=vLWxofP3U2xt1WrTkjX1Tw%3D%3D
2 | 1 | Advanced Photonix | Light Dependent Resistor | PDV-P9203 | Mouser | 846-PDV-P9203 | 0.88 | 0.88 | https://www.mouser.de/ProductDetail/Advanced-Photonix/PDV-P9203?qs=tlsG%2FOw5FFhjrO9EYnuJlg%3D%3D
3 | 1 | Seeedstudio | Xiao ESP32-S3 + Wio-SX1262 | 102010611 | Other | SEE-25675 | 11.68 | 11.68 | https://botland.store/lora-lorawan/25675-xiao-esp32-s3-wio-sx1262-kit-for-meshtastic-and-loralorawan-seeedstudio-102010611-4897068320128.html
4 | 1 | SOLDERED | Li-Ion Akku | 333284 | Reichelt | AKKU SOLD333284 | 8.57 | 8.57 | https://www.reichelt.de/de/de/shop/produkt/li-ion_akku_soldered_333284_1800_mah_3_7_v-373548
5 | 1 | Joy-It | Arduino Pressure Sensor 20g to 10 kg | SEN-PRESSURE10 | Reichelt | ARD SEN PRESSURE | 5.15 | 5.15 | https://www.reichelt.com/de/en/shop/product/arduino_-_pressure_sensor_20_g_to_10_kg-284398
6 | 1 | DFRobot | RP-L-170 Thin Pressure Sensor | SEN0295 | Mouser | 426-SEN0295 | 5.59 | 5.59 | https://www.mouser.de/ProductDetail/DFRobot/SEN0295
7 | 2 | Adafruit | Alpha MF02A-N-221-A01 FSR | 1075 | Mouser | 485-1075 | 6.66 | 13.32 | https://www.mouser.de/ProductDetail/Adafruit/1075?qs=GURawfaeGuDaOmXus2Zwlg%3D%3D
8 | 1 | Microchip | MCP6002 I/P Operationsverstärker Dual 1.8V 1MHz | MCP6002 | HSRW | 1715 | 0.41 | 0.41 | https://www.mouser.de/ProductDetail/Microchip-Technology/MCP6002-I-P?qs=sGAEpiMZZMsxiS4eJwGuBtZupmX4AUSq
9 | 1 | Joy-It | Load cell + amplifier | SEN-HX711-01 | Reichelt | DEBO HX711-01 | 6.40 | 6.40 | https://www.reichelt.com/de/en/shop/product/developer_boards_-_a_d_converter_-_balance-316296
10 |  |  |  |  |  |  |  | 0.00
11 |  |  |  |  |  |  |  | 0.00
12 |  |  |  |  |  |  |  | 0.00
13 |  |  |  |  |  |  |  | 0.00
14 |  |  |  |  |  |  |  | 0.00
15 |  |  |  |  |  |  |  | 0.00
 |  |  |  |  |  | total price* |  | 55.00
List of suitable vendors: |  |  |  |  |  | value added tax (VAT) |  | 10.45
shop |  | language | homepage |  |  | total price inclusive VAT: |  | 65.45
HSRW |  | en | https://ee.hsrw.org/
Mouser |  | en/de | https://www.mouser.de/
Reichelt |  | en/de | https://www.reichelt.de/ |  |  |  | *without value added tax (VAT)
Conrad |  | en/de | https://www.conrad.biz/
Other |  |  | only when absolutely necessary
Botland |  | en/de | https://botland.store/

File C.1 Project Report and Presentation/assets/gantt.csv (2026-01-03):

Outline Level | ID | Name | Start | Finish | Duration | % Complete | Predecessors | Resource Names | Color | Notes
1 | 1 | Project Ideation | 2025-10-09 | 2025-10-09 | 0 day | 100 |  |  |  | <p><br></p>
2 | 2 | Research project ideas | 2025-10-09 | 2025-10-09 | 1 day | 100 |  | Abhinav Kothari |  | <p><br></p>
2 | 3 | Decide on project idea | 2025-10-21 | 2025-10-21 | 1 day | 100 | 2FS | Justin Chin Cheong, Abhinav Kothari |  | <p><br></p>
1 | 4 | SAN Project Pitch | 2025-11-08 | 2025-11-08 | 0 day | 100 | 3FS | Abhinav Kothari |  | <p><br></p>
2 | 5 | LoRa Project Description | 2025-11-08 | 2025-11-08 | 1 day | 100 |  | Justin Chin Cheong, Abhinav Kothari |  | <p><br></p>
2 | 6 | LoRa Raw Schematics | 2025-11-09 | 2025-11-09 | 1 day | 100 | 5FS |  |  | <p><br></p>
2 | 7 | Create draft design for LoRa housing | 2025-11-10 | 2025-11-10 | 1 day | 100 | 6FS |  |  | <p><br></p>
2 | 8 | Conduct LoRa lit. review | 2025-12-29 | 2025-12-29 | 1 day | 100 | 7FS | Justin Chin Cheong |  | <p><br></p>
1 | 9 | SAN Bill of Materials | 2025-10-22 | 2025-10-22 | 0 day | 100 | 8FS | Justin Chin Cheong |  | <p><br></p>
2 | 10 | Choose exact sensors for LoRa | 2025-10-22 | 2025-10-22 | 1 day | 100 |  | Justin Chin Cheong, Abhinav Kothari |  | <p><br></p>
2 | 11 | Create a list of passives for sensors | 2025-10-23 | 2025-10-23 | 1 day | 100 | 10FS | Justin Chin Cheong, Abhinav Kothari |  | <p><br></p>
2 | 12 | Choose exact MCU + LoRa Transmitter | 2025-10-24 | 2025-10-24 | 1 day | 100 | 11FS | Justin Chin Cheong, Abhinav Kothari |  | <p><br></p>
1 | 13 | SAN Schematic Design | 2025-11-17 | 2025-11-17 | 0 day | 50 | 12FS |  |  | <p><br></p>
2 | 14 | Create fsd for LoRa system | 2025-11-17 | 2025-11-17 | 1 day | 100 |  |  |  | <p><br></p>
2 | 15 | Create functional schematic for LoRa system | 2025-11-18 | 2025-11-18 | 1 day | 100 | 14FS |  |  | <p><br></p>
2 | 16 | Create aesthetic schematic for LoRa | 2025-11-19 | 2025-11-19 | 1 day | 100 | 15FS |  |  | <p><br></p>
1 | 18 | SAN Software | 2025-12-11 | 2025-12-11 | 0 day | 100 | 17FS |  |  | <p><br></p>
2 | 19 | Configure comm w/ TTN | 2025-12-11 | 2025-12-11 | 1 day | 100 |  |  |  | <p><br></p>
3 | 20 | Set up light sensor reading | 2025-12-15 | 2025-12-15 | 1 day | 100 | 19FS | Justin Chin Cheong |  | <p><br></p>
3 | 21 | Set up tilt sensor reading | 2025-12-16 | 2025-12-16 | 1 day | 100 | 20FS | Justin Chin Cheong |  | <p><br></p>
3 | 22 | Set up weight sensor reading | 2025-12-17 | 2025-12-17 | 1 day | 100 | 21FS | Justin Chin Cheong |  | <p><br></p>
2 | 23 | Configure sensor datastream to TTN | 2025-12-18 | 2025-12-18 | 1 day | 100 | 22FS | Justin Chin Cheong |  | <p><br></p>
2 | 24 | Set-up back-end and notification system | 2025-12-19 | 2025-12-19 | 1 day | 100 | 23FS | Abhinav Kothari |  | <p><br></p>
3 | 25 | Read info from TTN stream | 2025-12-20 | 2025-12-20 | 1 day | 100 | 24FS | Abhinav Kothari |  | <p><br></p>
3 | 26 | Set up sensor logic for open detection | 2025-12-21 | 2025-12-21 | 1 day | 100 | 25FS | Abhinav Kothari |  | <p><br></p>
1 | 27 | SAN Project Report | 2025-11-16 | 2025-11-16 | 0 day | 50 | 26FS |  |  | <p><br></p>
2 | 28 | Create LoRa LaTeX template | 2025-11-16 | 2025-11-16 | 1 day | 100 |  |  |  | <p><br></p>
2 | 29 | Write LoRa introduction | 2025-11-17 | 2025-11-17 | 1 day | 0 | 28FS | Abhinav Kothari |  | <p><br></p>
2 | 30 | Write LoRa lit. review | 2025-12-30 | 2025-12-30 | 1 day | 100 | 29FS | Justin Chin Cheong |  | <p><br></p>
2 | 31 | Write Theory section for LoRa | 2025-12-31 | 2025-12-31 | 1 day | 100 | 30FS | Abhinav Kothari |  | <p><br></p>
2 | 32 | Write LoRa system design process | 2026-01-01 | 2026-01-01 | 1 day | 0 | 31FS | Justin Chin Cheong |  | <p><br></p>
2 | 33 | Write LoRa discussion of design | 2026-01-02 | 2026-01-02 | 1 day | 100 | 32FS | Abhinav Kothari |  | <p><br></p>
2 | 34 | Write LoRa conclusion | 2026-01-03 | 2026-01-03 | 1 day | 0 | 33FS | Justin Chin Cheong |  | <p><br></p>
1 | 35 | SAN Presentation | 2026-01-04 | 2026-01-04 | 0 day | 0 | 34FS |  |  | <p><br></p>
2 | 36 | Outline sections of LoRa presentation | 2026-01-05 | 2026-01-05 | 1 day | 0 |  |  |  | <p><br></p>
2 | 37 | Create intro to LoRa presentation | 2026-01-06 | 2026-01-06 | 1 day | 0 | 36FS |  |  | <p><br></p>

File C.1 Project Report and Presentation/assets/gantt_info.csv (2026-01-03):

Outline Level | ID | Name | Start | Finish | Duration | % Complete | Predecessors | Resource Names | Color | Notes
1 | 1 | Project Ideation | 9-Oct-25 | 9-Oct-25 | 0 day | 100 |  |  |  | <p><br></p>
2 | 2 | Research project ideas | 9-Oct-25 | 9-Oct-25 | 1 day | 100 |  | Abhinav Kothari |  | <p><br></p>
2 | 3 | Decide on project idea | 21-Oct-25 | 21-Oct-25 | 1 day | 100 | 2FS | Justin Chin Cheong, Abhinav Kothari |  | <p><br></p>
1 | 4 | SAN Project Pitch | 8-Nov-25 | 8-Nov-25 | 0 day | 100 | 3FS | Abhinav Kothari |  | <p><br></p>
2 | 5 | LoRa Project Description | 8-Nov-25 | 8-Nov-25 | 1 day | 100 |  | Justin Chin Cheong, Abhinav Kothari |  | <p><br></p>
2 | 6 | LoRa Raw Schematics | 9-Nov-25 | 9-Nov-25 | 1 day | 100 | 5FS |  |  | <p><br></p>
2 | 7 | Create draft design for LoRa housing | 10-Nov-25 | 10-Nov-25 | 1 day | 100 | 6FS |  |  | <p><br></p>
2 | 8 | Conduct LoRa lit. review | 29-Dec-25 | 29-Dec-25 | 1 day | 100 | 7FS | Justin Chin Cheong |  | <p><br></p>
1 | 9 | SAN Bill of Materials | 22-Oct-25 | 22-Oct-25 | 0 day | 100 | 8FS | Justin Chin Cheong |  | <p><br></p>
2 | 10 | Choose exact sensors for LoRa | 22-Oct-25 | 22-Oct-25 | 1 day | 100 |  | Justin Chin Cheong, Abhinav Kothari |  | <p><br></p>
2 | 11 | Create a list of passives for sensors | 23-Oct-25 | 23-Oct-25 | 1 day | 100 | 10FS | Justin Chin Cheong, Abhinav Kothari |  | <p><br></p>
2 | 12 | Choose exact MCU + LoRa Transmitter | 24-Oct-25 | 24-Oct-25 | 1 day | 100 | 11FS | Justin Chin Cheong, Abhinav Kothari |  | <p><br></p>
1 | 13 | SAN Schematic Design | 17-Nov-25 | 17-Nov-25 | 0 day | 50 | 12FS |  |  | <p><br></p>
2 | 14 | Create fsd for LoRa system | 17-Nov-25 | 17-Nov-25 | 1 day | 100 |  |  |  | <p><br></p>
2 | 15 | Create functional schematic for LoRa system | 18-Nov-25 | 18-Nov-25 | 1 day | 100 | 14FS |  |  | <p><br></p>
2 | 16 | Create aesthetic schematic for LoRa | 19-Nov-25 | 19-Nov-25 | 1 day | 100 | 15FS |  |  | <p><br></p>
1 | 18 | SAN Software | 11-Dec-25 | 11-Dec-25 | 0 day | 100 | 17FS |  |  | <p><br></p>
2 | 19 | Configure comm w/ TTN | 11-Dec-25 | 11-Dec-25 | 1 day | 100 |  |  |  | <p><br></p>
3 | 20 | Set up light sensor reading | 15-Dec-25 | 15-Dec-25 | 1 day | 100 | 19FS | Justin Chin Cheong |  | <p><br></p>
3 | 21 | Set up tilt sensor reading | 16-Dec-25 | 16-Dec-25 | 1 day | 100 | 20FS | Justin Chin Cheong |  | <p><br></p>
3 | 22 | Set up weight sensor reading | 17-Dec-25 | 17-Dec-25 | 1 day | 100 | 21FS | Justin Chin Cheong |  | <p><br></p>
2 | 23 | Configure sensor datastream to TTN | 18-Dec-25 | 18-Dec-25 | 1 day | 100 | 22FS | Justin Chin Cheong |  | <p><br></p>
2 | 24 | Set-up back-end and notification system | 19-Dec-25 | 19-Dec-25 | 1 day | 100 | 23FS | Abhinav Kothari |  | <p><br></p>
3 | 25 | Read info from TTN stream | 20-Dec-25 | 20-Dec-25 | 1 day | 100 | 24FS | Abhinav Kothari |  | <p><br></p>
3 | 26 | Set up sensor logic for open detection | 21-Dec-25 | 21-Dec-25 | 1 day | 100 | 25FS | Abhinav Kothari |  | <p><br></p>
1 | 27 | SAN Project Report | 16-Nov-25 | 16-Nov-25 | 0 day | 50 | 26FS |  |  | <p><br></p>
2 | 28 | Create LoRa LaTeX template | 16-Nov-25 | 16-Nov-25 | 1 day | 100 |  |  |  | <p><br></p>
2 | 29 | Write LoRa introduction | 17-Nov-25 | 17-Nov-25 | 1 day | 0 | 28FS | Abhinav Kothari |  | <p><br></p>
2 | 30 | Write LoRa lit. review | 30-Dec-25 | 30-Dec-25 | 1 day | 100 | 29FS | Justin Chin Cheong |  | <p><br></p>
2 | 31 | Write Theory section for LoRa | 31-Dec-25 | 31-Dec-25 | 1 day | 100 | 30FS | Abhinav Kothari |  | <p><br></p>
2 | 32 | Write LoRa system design process | 1-Jan-26 | 1-Jan-26 | 1 day | 0 | 31FS | Justin Chin Cheong |  | <p><br></p>
2 | 33 | Write LoRa discussion of design | 2-Jan-26 | 2-Jan-26 | 1 day | 100 | 32FS | Abhinav Kothari |  | <p><br></p>
2 | 34 | Write LoRa conclusion | 3-Jan-26 | 3-Jan-26 | 1 day | 0 | 33FS | Justin Chin Cheong |  | <p><br></p>
1 | 35 | SAN Presentation | 4-Jan-26 | 4-Jan-26 | 0 day | 0 | 34FS |  |  | <p><br></p>
2 | 36 | Outline sections of LoRa presentation | 5-Jan-26 | 5-Jan-26 | 1 day | 0 |  |  |  | <p><br></p>
2 | 37 | Create intro to LoRa presentation | 6-Jan-26 | 6-Jan-26 | 1 day | 0 | 36FS |  |  | <p><br></p>

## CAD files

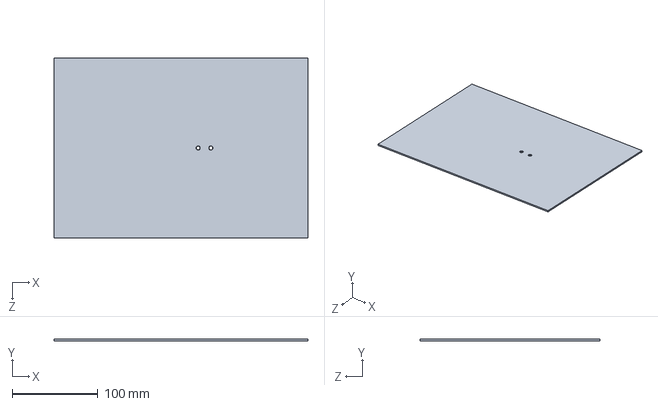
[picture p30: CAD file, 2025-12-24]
B.3 Models/v2.0/BasePlate.SLDPRT
297.0 x 2.00 x 210.0 mm

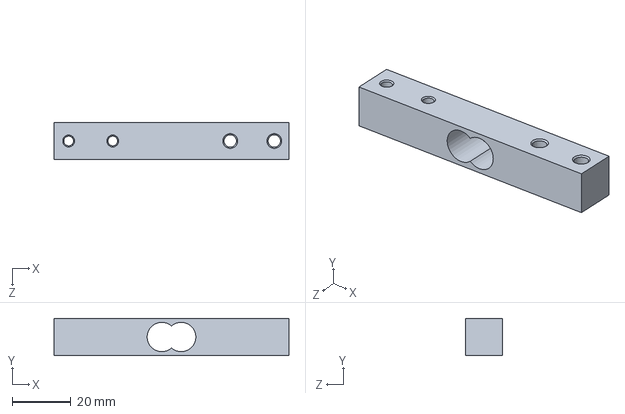
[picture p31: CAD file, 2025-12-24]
B.3 Models/v2.0/LoadCell.SLDPRT
80.0 x 12.7 x 12.7 mm

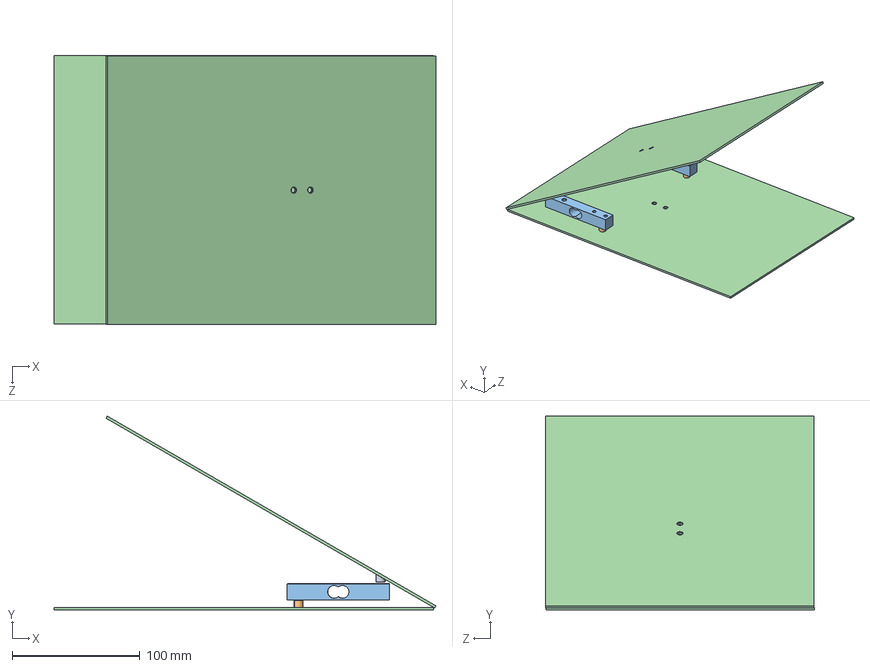
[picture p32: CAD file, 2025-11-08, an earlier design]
B.3 Models/v0.0/Assembly.SLDASM
298.9 x 151.7 x 210.1 mm
BasePlate x 2
LoadCell x 2
SupportForLoadCell x 2
SupportForLoadCellSlant x 2

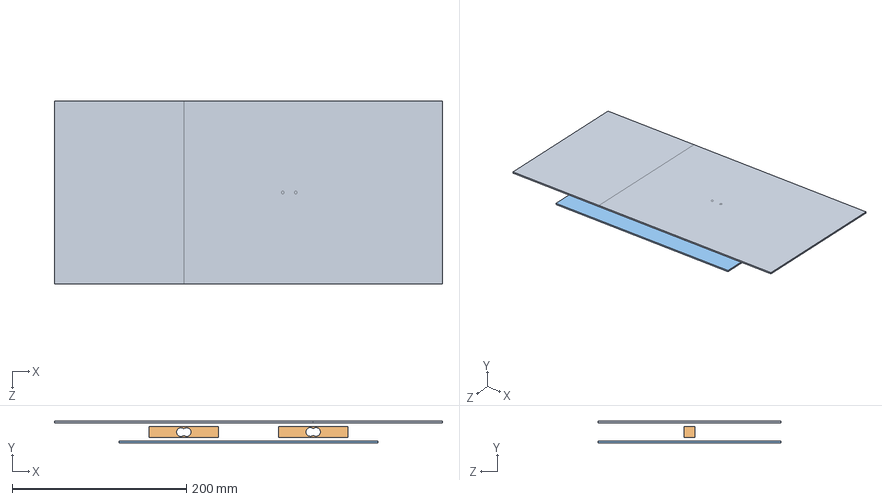
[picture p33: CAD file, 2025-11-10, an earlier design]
B.3 Models/v1.0/Assembly.SLDASM
445.5 x 25.0 x 210.0 mm
BasePlate
LoadCell x 2
TopPlate x 2

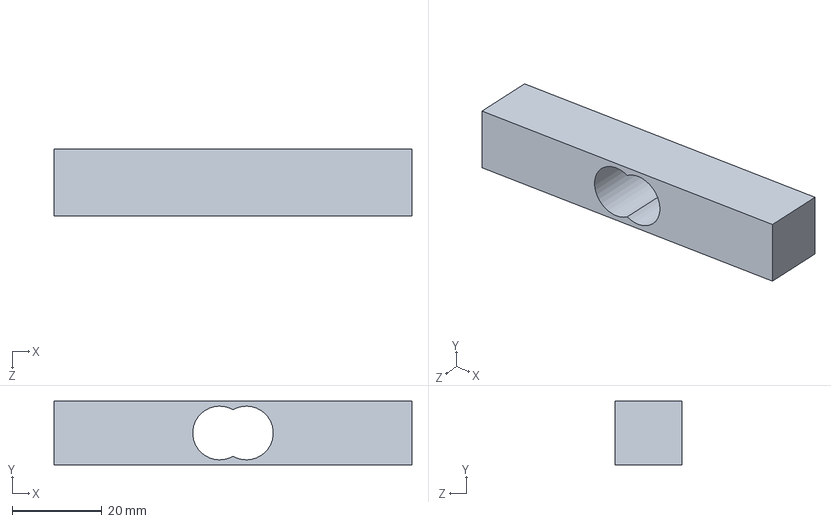
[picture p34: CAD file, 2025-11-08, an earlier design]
B.3 Models/v0.0/LoadCell.SLDPRT
80.0 x 14.2 x 15.0 mm

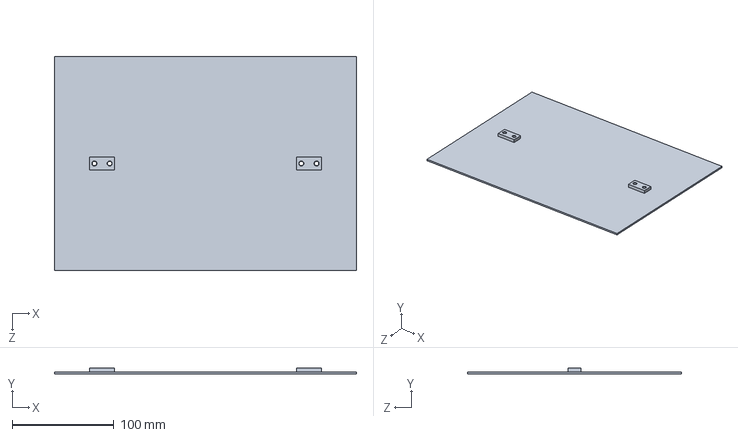
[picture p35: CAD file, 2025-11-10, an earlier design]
B.3 Models/v1.0/BasePlate.SLDPRT
297.0 x 6.00 x 210.0 mm

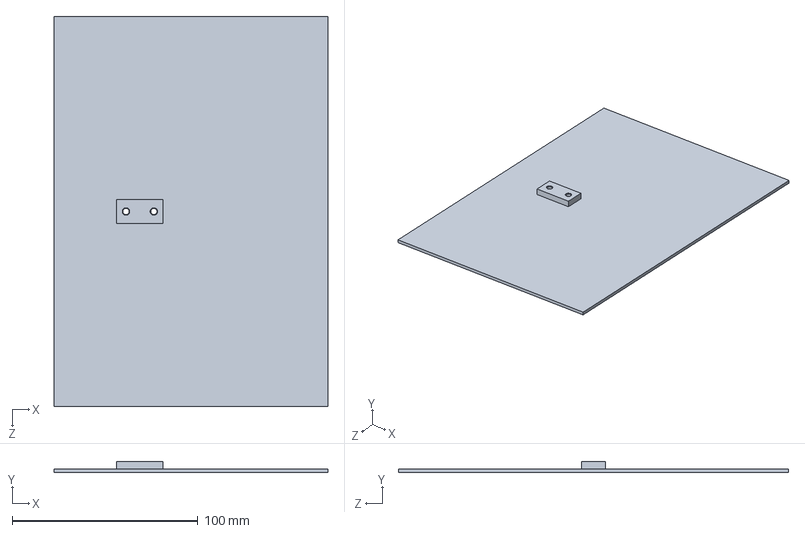
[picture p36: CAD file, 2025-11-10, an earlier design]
B.3 Models/v1.0/TopPlate.SLDPRT
147.5 x 6.00 x 210.0 mm

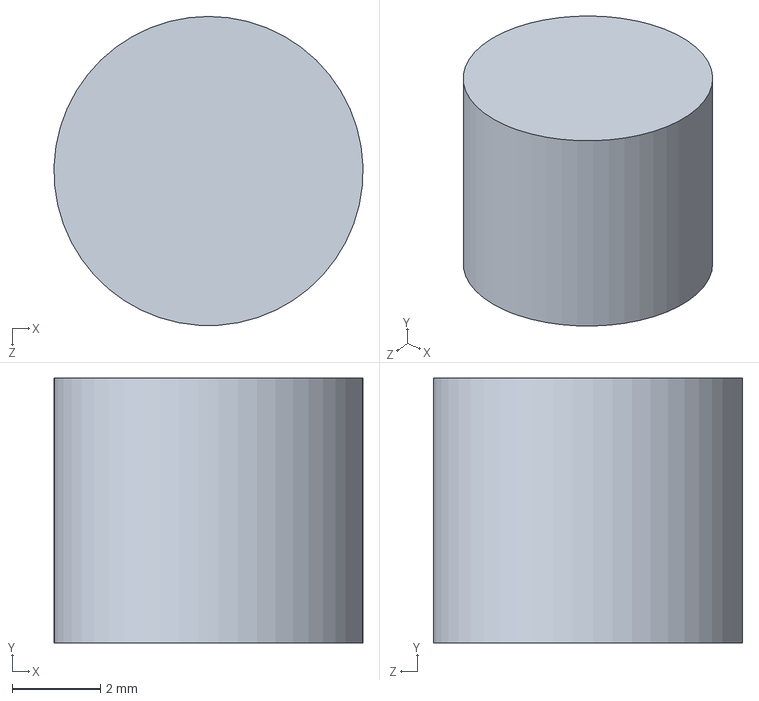
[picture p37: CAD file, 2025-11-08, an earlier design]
B.3 Models/v0.0/SupportForLoadCell.SLDPRT
7.00 x 6.00 x 7.00 mm

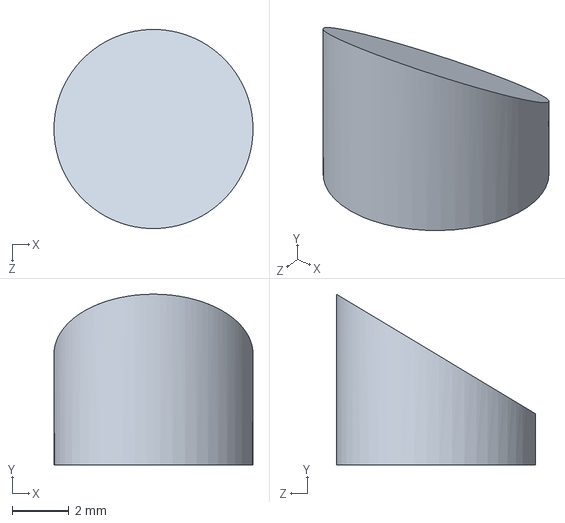
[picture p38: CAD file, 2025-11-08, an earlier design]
B.3 Models/v0.0/SupportForLoadCellSlant.SLDPRT
7.00 x 6.00 x 7.00 mm

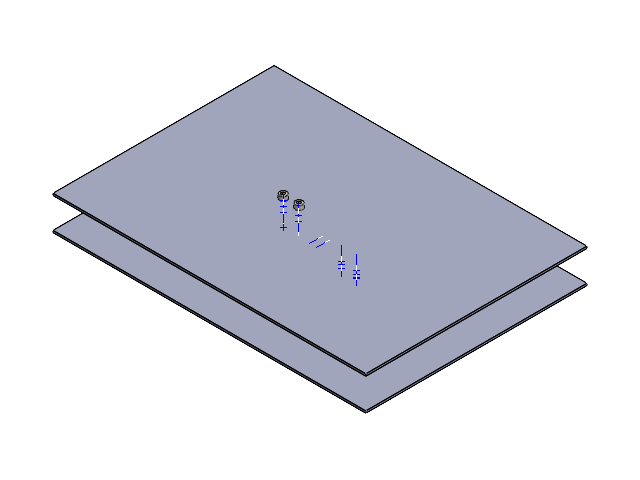
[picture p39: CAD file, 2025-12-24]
B.3 Models/v2.0/Assembly.SLDASM
BasePlate
LoadCell
TopPlate
hex nut style 1 gradeab_iso x 8
socket head cap screw_iso x 4

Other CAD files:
B.3 Models/v2.0/TopPlate.SLDPRT
B.3 Models/v0.0/BasePlate.SLDPRT
B.3 Models/v1.0/LoadCell.SLDPRT

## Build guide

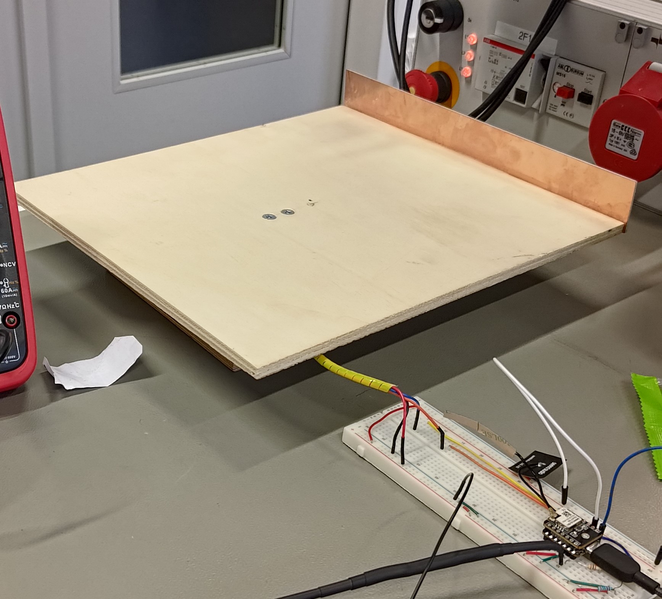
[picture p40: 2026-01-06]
C.1 Project Report and Presentation/assets/weight-sensor_construction-2.jpg

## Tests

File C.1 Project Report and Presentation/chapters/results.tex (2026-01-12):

\section{Results}
\label{sec: results}
%%%%%%%%%%%%%%%%%%%%%%%%%%%%%%%%%%%%%%%%%%%%%%%%%%%%%%%%%%%%%%%%%%%%%%%%%%%%%%%%%%%%%%%%%%%%%%%%%%%%%%%%%%%%%%%%%%%%%%%%
\subsection{Complete System}
\label{sec: completeSystem}
The completely assembled system can be seen in Figure \ref{fig: finalProduct}. A short demonstration video of the system in action can be found at the following link: \url{https://youtube.com/shorts/1nNW60RcUi4}.
\begin{figure}[ht]
    \begin{subfigure}{0.48\textwidth}
        \centering
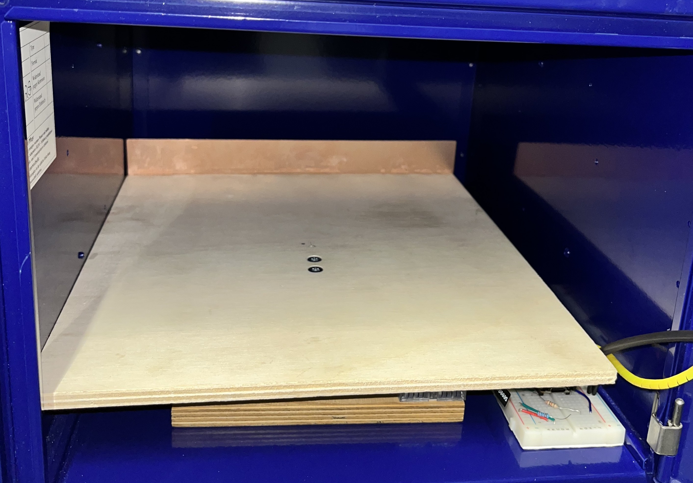
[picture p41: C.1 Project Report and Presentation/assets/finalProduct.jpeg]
        
        \caption{Front View}
        \label{fig: finalProductFront}                   
    \end{subfigure}
    \begin{subfigure}{0.48\textwidth}
        \centering
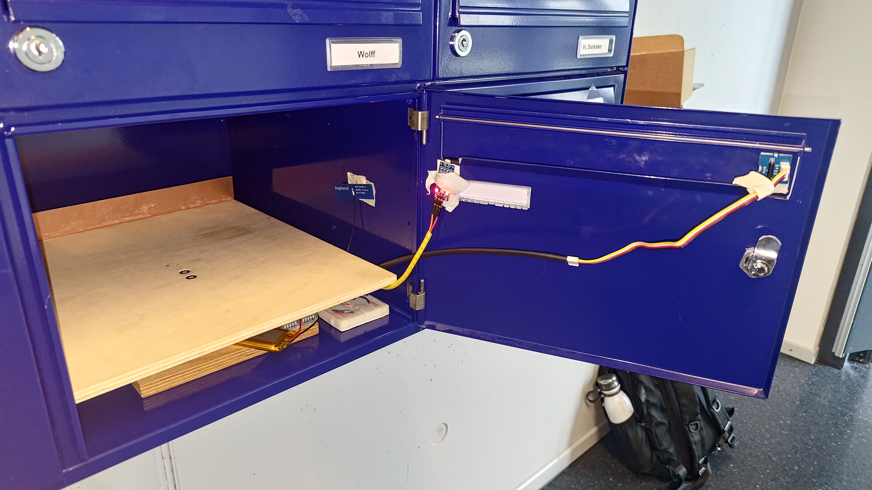
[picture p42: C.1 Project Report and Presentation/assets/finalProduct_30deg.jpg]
        
        \caption{Side View}
        \label{fig: finalProduct30deg}                   
    \end{subfigure}
    \caption{Final Product Inside the Post Box}
    \label{fig: finalProduct}
\end{figure}
%%%%%%%%%%%%%%%%%%%%%%%%%%%%%%%%%%%%%%%%%%%%%%%%%%%%%%%%%%%%%%%%%%%%%%%%%%%%%%%%%%%%%%%%%%%%%%%%%%%%%%%%%%%%%%%%%%%%%%%%
\subsection{Issues}
\label{sec: issues}
\subsubsection{TTN Re-join Issue}
\label{sec: ttnRejoinIssue}
The most significant issue faced during the project was with The Things Network (TTN) and the LoRaWAN re-join process. After successfully joining the network for the first time, whenever the device was put to sleep or restarted, it took increasingly longer and longer to re-join the network, sometimes taking upwards of 30 minutes. The error message in the TTN console simply said \cmd{Devnonces too small}. This was a major hindrance to testing and development, as every time the code was modified and re-uploaded, the device had to re-join the network. 

\bigskip

Through extensive research, a number of potential solutions were attempted before the issue was resolved. Firstly, the LoRaWAN specification in the TTN configuration was changed from 1.1.3 to 1.0.4 as this form has more relaxed security requirements. This only resolve the issue for a few power cycles. Next, the RadioLib library was upgraded to the latest version, which required a reworking of most of the LoRaWAN configuration code. This also did not resolve the issue. Finally, it was discovered that the issue was due to the DevNonce value being reset to 0 on every power cycle. This was fixed by storing the DevNonce value in the non-volatile memory of the microcontroller and incrementing it on every join attempt. This solution finally resolved the issue, allowing for quick re-joining on subsequent power cycles as discussed in Section \ref{sec: loraConfig}. 

\subsubsection{Issues with static IP and hosting}
\label{sec: issuesWithStaticIPAndHosting}
The server was initally hosted locally, however to provide access to the user over the web, a public IP address was required. This was also meant to be static, so user can always access the server
without having to worry about changing IP addresses. This is what led to the use of ngrok, which allows for a static IP address to be used. However, this meant the user had to run multiple scripts to start the server. 
Which can be annoying for a non technical user. 

\bigskip

To combat this issue, a .bat file was created, which runs all the necessary commands to start the server and ngrok tunnel. This allows the user to just double click the .bat file and have everything start automatically. This also helps us solve another issue, which is incase the required python libraries are not installed, the script checks 
for them and installs them if they are missing. It also hides all ngrok instances, to prevent confusion. The bat script contents can be seen in Listing \ref{lst: batScript}
\begin{lstlisting}[breaklines=true, caption={.bat Script to start server and ngrok}, label={lst: batScript}]
@echo off
title Smart Mailbox Dashboard
color 0A

echo ========================================================
echo          SMART MAILBOX PROJECT LAUNCHER
echo ========================================================
echo.

:: --- STEP 1: INSTALL/UPDATE REQUIREMENTS ---
echo [1/4] Checking Python libraries...
pip install flask python-dotenv
if %errorlevel% neq 0 (
    color 0C
    echo.
    echo [ERROR] Python or PIP is not installed or not in your PATH.
    echo Please install Python from python.org and try again.
    pause
    exit /b
)
echo Libraries are ready.
echo.

:: --- STEP 2: CHECK CONFIGURATION ---
echo [2/4] Checking configuration file...
if not exist .env (
    color 0E
    echo.
    echo [WARNING] .env file was not found!
    echo I have created a template .env file for you.
    echo Please open ".env", add your passwords, and run this script again.
    
    :: Create a default .env file
    echo SERVER_PORT=3000> .env
    echo AUTH_TOKEN=BC5FB17A739C64639751B59209E07F88>> .env
    echo EMAIL_SENDER=my-iot-project@gmail.com>> .env
    echo EMAIL_PASSWORD=REPLACE_WITH_APP_PASSWORD>> .env
    echo EMAIL_RECIPIENT=your_personal_email@gmail.com>> .env
    
    pause
    exit /b
)
echo Configuration found.
echo.

:: --- STEP 3: START NGROK (NEW WINDOW) ---
echo [3/4] Launching Ngrok Tunnel...
:: This opens a separate popup window for Ngrok so it doesn't block the script
start "Ngrok Tunnel" ngrok http --domain=unarithmetically-peppiest-libbie.ngrok-free.dev 3000

:: --- STEP 4: START PYTHON SERVER ---
echo [4/4] Starting Python Server...
echo.
echo ========================================================
echo    Dashboard: https://unarithmetically-peppiest-libbie.ngrok-free.dev
echo    Local:     http://localhost:3000
echo    Status:    RUNNING (Keep this window open)
echo ========================================================
echo.

python server.py

:: If python crashes, keep window open to see error
pause
\end{lstlisting}

However, this is still not an ideal solution, as the user still has to run the .bat file manually, must have python 
installed on their machine and most importantly run the server continuously. A better solution would be to host the server on a local raspberry pi or similar device, which can run the server 24/7 without any user intervention. This would also eliminate the need for ngrok, as the raspberry pi can be given a static IP address. 
%%%%%%%%%%%%%%%%%%%%%%%%%%%%%%%%%%%%%%%%%%%%%%%%%%%%%%%%%%%%%%%%%%%%%%%%%%%%%%%%%%%%%%%%%%%%%%%%%%%%%%%%%%%%%%%%%%%%%%%%
\subsection{Validation Results}
\label{sec: validationResults}
The results from the validation tests described in Section \ref{sec: validationMethods} are summarized below.

\subsubsection{Mail Detection}
\label{sec: mailDetectionResults}
The system was able to successfully detect 10 out of 10 objects, resulting in a detection accuracy of 100\%. Classification accuracy on the other hand was 80\%, with 8 out of 10 objects being correctly classified into light, medium, and heavy categories. The misclassifications occurred for a stack of papers and a pack of cards. Both objects had weights close to the classification thresholds, leading to incorrect categorization.

\subsubsection{Email Notification}
\label{sec: emailNotificationResults}
The system was able to successfully send email notifications in all 9 test cases. However, events were only classified accurately 7 out of 9 times. The 2 misclassifications were no mail notifications being sent when mail was placed inside. This was due to the weight being read before the mail landed on the platform. To compensate this issue, a delay of 25 seconds was added before reading the weight after mail detection as mentioned in Section \ref{sec: mailDetectionLogic}. It was also found that the entire mail detection event from lid opening to email receipt took approximately 65 seconds on average.

\subsubsection{Battery Life}
\label{sec: batteryLifeResults}
It was found that during an uplink event, the system drew a peak current of 39.5mA on average. While in deep sleep mode, the system drew around 7.25mA on average. This is likely due to the power consumption of the sensors. Using these values, the average current consumption over a 24 hour period can be calculated using the equations below. Assuming 4 mail events per day, each taking 65 seconds, and a battery capacity of 1800mAh, the estimated battery life is approximately 10 days.
\begin{equation}
    I_{awake}^{avg}=\frac{4\cdot39.5mA\cdot65s}{24h\cdot3600\frac{s}{h}}=118.86\mu A
\end{equation}
\begin{equation}
    I_{sleep}^{avg}=\frac{(24h\cdot3600\frac{s}{h}-65s\cdot4)\cdot7.25mA}{24h\cdot3600\frac{s}{h}}=7.23mA
\end{equation}
\begin{equation}
    T=\frac{1800mAh}{7.23mA + 0.11886mA}=244.94 h \approx10days
\end{equation}

Interestingly, the battery life of the system can be very easily extended by using any power bank and a USB-C cable. This is because the XIAO ESP32-S3 has an on board USB-C port which allows for convenient powering. Also, most commercially power banks have a much larger capacity than the 1800mAh battery used in this project. This can be seen in Figure \ref{fig: finalProductWithPowerBank}, where the system is powered by a power bank. Using a power bank with a capacity of 10000mAh, the estimated battery life extends to approximately 55 days.

\begin{figure}[h!]
    \centering
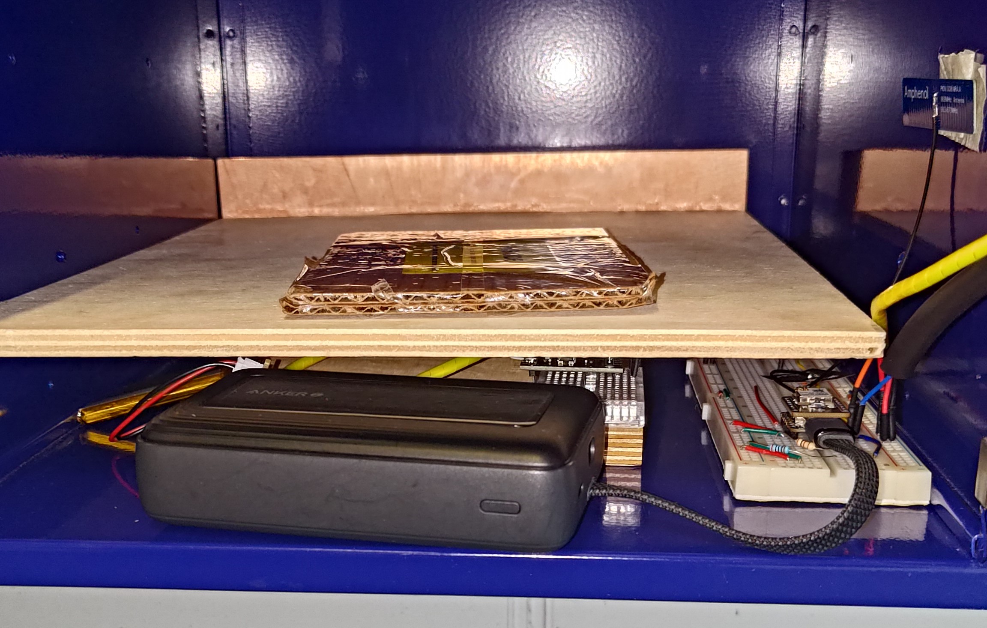
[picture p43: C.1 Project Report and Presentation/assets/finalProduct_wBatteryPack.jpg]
    
    \caption{Final Product Powered by a Power Bank}
    \label{fig: finalProductWithPowerBank}
\end{figure}
%%%%%%%%%%%%%%%%%%%%%%%%%%%%%%%%%%%%%%%%%%%%%%%%%%%%%%%%%%%%%%%%%%%%%%%%%%%%%%%%%%%%%%%%%%%%%%%%%%%%%%%%%%%%%%%%%%%%%%%%

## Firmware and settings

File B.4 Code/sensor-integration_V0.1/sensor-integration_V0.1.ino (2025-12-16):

/*
@author: Justin Chin Cheong (34140) and Abhinav Kothari (33349)
@desc: Sketch to test integration of all sensors at once
@version: V0.1 - update to make the sensors read continuously and process system logic
*/
// ############################### Libraries ######################################
#include <Arduino.h>
#include <HX711.h>

// ############################### Configuration and Definitions ##################
// Pins
#define LIGHT_SENSOR_PIN 2
#define LOADCELL_DOUT_PIN 43
#define LOADCELL_SCK_PIN 6
#define TILT_SENSOR_PIN 44

// Define IDs for payload encoding 
#define ID_WEIGHT_SENSOR 0x01
#define ID_LIGHT_SENSOR 0x02
#define ID_TILT_SENSOR 0x03   

// ############################### Data Structure ################################
// A simple struct to hold one sensor's reading
struct SensorReading
{
    uint8_t id;    // Unique for each sensor ID 
    uint8_t value; // The actual value 
};
// ############################### Variables ######################################
// Variables for Weight Sensor
HX711 scale;
uint8_t weightState_curr = 0;
uint8_t weightState_prev = 0;


// ############################### Functions ######################################
void sensorManager_init() {
  // Weight Sensor
  scale.begin(LOADCELL_DOUT_PIN, LOADCELL_SCK_PIN); // initiliase weight sensor
  scale.set_scale(940.f); // Set the default (calibrated against scale)
  scale.tare();
  scale.power_down(); // Put HX711 to sleep to save power
  delay(500);

  // Light Sensor
  pinMode(LIGHT_SENSOR_PIN, INPUT); // Input mode for light sensor

  // Tilt Sensor
  pinMode(TILT_SENSOR_PIN, INPUT); // Input mode for light sensor

  // End Intialisation
  Serial.println("Sensor Manager Initialized.");
}

SensorReading readWeightSensor() {
  scale.power_up(); // Wake HX711 from sleep
  delay(500); // short delay to ensure it wakes in time
  int weightState = 0;
  long weight = 0;
  long weight_thres = 5.0; // Threshold [g] at which sensor alerts system
  
  SensorReading reading;
  reading.id = ID_WEIGHT_SENSOR; 

  if (scale.is_ready()) {
    weight = scale.get_units(10); // Average of 10 readings normalised (based on calibration)
    if (weight > weight_thres) { // If weight is above our threshold
      weightState = 1;
    } else {
      weightState = 0;
    }
  } else {
    Serial.println("HX711 not found.");
  }

  reading.value = (uint8_t)weightState; //storing state value

  Serial.print("[Sensor 0x01] Weight: ");
  Serial.print(weight);
  Serial.print(" Weight State: ");
  Serial.println(weightState == HIGH ? "ON (1)" : "OFF (0)");

  scale.power_down(); // Put HX711 to sleep to save power
  delay(500);
  return reading;
}

SensorReading readLightSensor() {
  SensorReading reading;
  reading.id = ID_LIGHT_SENSOR; 
  
  int lightState = !digitalRead(LIGHT_SENSOR_PIN);
  reading.value = (uint8_t)lightState;

  Serial.print("[Sensor 0x02] Light State: ");
  Serial.println(lightState == HIGH ? "ON (1)" : "OFF (0)");
  
  return reading;
}

SensorReading readTiltSensor() {
  SensorReading reading;
  reading.id = ID_TILT_SENSOR; 
  
  int tiltState = digitalRead(TILT_SENSOR_PIN);
  reading.value = (uint8_t)tiltState;

  Serial.print("[Sensor 0x03] Tilt State: ");
  Serial.println(tiltState == HIGH ? "ON (1)" : "OFF (0)");
  
  return reading;
}
// ############################### Setup ######################################
void setup() {
  Serial.begin(115200);
  sensorManager_init();
  SensorReading weightReading = readWeightSensor();
  weightState_prev = weightReading.value; // initial weight state (is there paper or not)
}
// ############################### Main Loop ######################################
void loop() {
  // Read Sensors to detect box opening
  SensorReading lightReading = readLightSensor();
  SensorReading tiltReading = readTiltSensor();

  if (lightReading.value && tiltReading.value) { // Box Open
    delay(5000); // Wait for mail to be placed
    SensorReading weightReading = readWeightSensor(); // read the weight sensor value
    weightState_curr = weightReading.value;
    if (weightState_curr == weightState_prev) { // if no change, then someone is peaking 👀
      Serial.println("Tampering Detecting");
    } else { // If state changed, look at if mail added or removed 
      Serial.print("Mail was ");
      Serial.println(weightState_curr == HIGH ? "Added" : "Removed"); // Mail is there?
    }
    weightState_prev = weightState_curr; // update weight state
  } 
  delay(1500);
}

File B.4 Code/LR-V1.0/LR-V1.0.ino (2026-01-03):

/*
@author: Justin Chin Cheong (34140) and Abhinav Kothari (33349)
@desc: Complete Script for the Talking Mailbox Project to read all sensors and send data via LoRaWAN to the TTN
@version: V1.0 - fully operational prototype w/ sensors, LoRaWAN 1.0.4, deep sleep, battery monitoring, mail categorization
*/

// ############################### Libraries ######################################
#include "LoRaConfig.h"
#include "SensorManager.h"

// ############################### Setup ######################################
void setup()
{
  Serial.begin(115200);

  // Initialising all the Sensors
  sensorManager_init();

  // Radio Setup
  Serial.println(F("\nSetup... "));

  Serial.println(F("Initialise the radio"));
  int16_t state = radio.begin();
  debug(state != RADIOLIB_ERR_NONE, F("Initialise radio failed"), state, true);

  // SX1262 rf switch order: setRfSwitchPins(rxEn, txEn);
  radio.setRfSwitchPins(38, RADIOLIB_NC);

  // Activating the node for LoRaWAN
  state = lwActivate();
  Serial.println(F("Ready!\n")); // Ready to begin uploading

  // Reading Sensors and Building in Payload
  uplinkPayloadLen = detectMail(uplinkPayload);

  // Uploading the Payload
  state = lwUplink(uplinkPayload);

  delay(5000);

  // Sleep
  radio.sleep();
  goToSleep();
}
// ############################### Main Loop ######################################
void loop()
{
  // Empty since sleep interrupt operates as the loop
}

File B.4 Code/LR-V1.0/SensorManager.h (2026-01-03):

// SensorManager.h

#ifndef SENSOR_MANAGER_H
#define SENSOR_MANAGER_H

// ############################### Library ######################################
#include <Arduino.h>
#include <HX711.h>

// ############################### Configuration and Definitions ##################
// Pins
#define LIGHT_SENSOR_PIN 2
#define LOADCELL_DOUT_PIN 43
#define LOADCELL_SCK_PIN 6
#define TILT_SENSOR_PIN 1
#define BAT_MONITOR_PIN 3

// Define IDs for payload encoding
#define ID_DEVICE 0x33
#define ID_WEIGHT_SENSOR 0x01
#define ID_LIGHT_SENSOR 0x02
#define ID_TILT_SENSOR 0x03
#define ID_TAMPERING 0x04
#define ID_HEAVY_MAIL 0x05
#define ID_MEDIUM_MAIL 0x06
#define ID_LIGHT_MAIL 0x07
#define ID_NO_MAIL 0x08
#define ID_BAT_MONITOR 0x09

// ############################### Data Structure ################################
// A simple struct to hold one sensor's reading
struct SensorReading
{
    uint8_t id;    // Unique for each sensor ID
    uint8_t value; // The actual value
};

// ############################### Functions ####################################

/**
 * @brief Initializes all sensor pins and hardware interfaces
 */
void sensorManager_init();

/**
 * @brief Reads the HX711 weight sensor
 * @return A SensorReading struct containing the weight sensor's data.
 */
SensorReading readWeightSensor();

/**
 * @brief Reads the Digital Light Sensor.
 * @return A SensorReading struct containing the light sensor's data.
 */
SensorReading readLightSensor();

/**
 * @brief Reads the Digital Light Sensor.
 * @return A SensorReading struct containing the tilt sensor's data.
 */
SensorReading readTiltSensor();

/**
 * @brief Reads the Level of the Battery
 * @return A SensorReading struct containing the battery monitor data.
 */
SensorReading batteryMonitor();

/**
 * @brief Puts MCU to sleep and sets pins for wake up
 */
void goToSleep();

/**
 * @brief Checks sensors for if new mail is added and builds the LoRaWAN payload.
 * @param payloadBuffer The buffer to write the payload bytes into.
 * @return The length of the resulting payload in bytes.
 */
uint16_t detectMail(uint8_t *payloadBuffer);

#endif // SENSOR_MANAGER_H

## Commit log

2025-10-22 Pitch + BOM Setup
    [SAN_Project_Partslist.xlsx]
2025-10-22 Minor tweaks
    [SAN_Project_Partslist.xlsx]
2025-10-22 +PressureSensors
    + some sensor options we can experiment with
    + an op amp
    [SAN_Project_Partslist.xlsx]
2025-10-22 Added load cell + amplifier from DEBO
    [SAN_Project_Partslist.xlsx]
2025-10-23 another version with only modules
    [SAN_Project_Partslistv2.xlsx]
2025-10-23 Added another version of partslist with modules instead
    [SAN_Project_Partslistv2.xlsx]
2025-11-08 Schematic and Pitch Prez Update
    [SAN_Project_Partslistv2.xlsx]
2025-11-08 Very rough idea of the model
    [Assembly.SLDASM, BasePlate.SLDPRT, LoadCell.SLDPRT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]
2025-11-10 Model Idea Changed Load Cell
    The updated model idea for paper detection via load cell
    [Assembly.SLDASM, BasePlate.SLDPRT, LoadCell.SLDPRT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]
2025-11-10 Added new version load paper detection
    [Assembly.SLDASM, BasePlate.SLDPRT, LoadCell.SLDPRT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]
2025-11-10 Small tweaks to pitch
2025-12-11 LoRa w/ Light Sensor Works
2025-12-13 Setup for all sensors to stream via LoRa + HX711 library
2025-12-15 sensor-integration 2 versions
    I made the sensors work to just detect status constatnly and send to TTN
    I also did a simple logic version which checks when the box is opened before reading the load cell and then can transmit (haven't done the transmission yet)
2025-12-16 new sensor logic w/ LoRa - working
2025-12-17 Battery Monitor
2025-12-18 Deep Sleep and Sensor Logic works
2025-12-19 Final tweaks to server
    -Now allows us to select recipents based on device ID
    -Battery information added
    -Comments changes
    -Minor quality of life features (I dont remember all I added)
2025-12-19 Fixing Tare issue + power consumption calculcations
    [LoRa_power-consumption.xlsx]
2025-12-29 Updated Schematic + Literature Review
2025-12-30 Some progress in the report
    - we may need to change structure
    [LoRa_BOM.xlsx, LoRa_power-consumption.xlsx, gantt.csv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]
2026-01-08 More info in the report
    added validation methods including power consumption and estimated battery life
2026-01-11 Prez updates
    + better flowchart
    - tare issue and other slides
    + basic script outline
    [gantt.csv, gantt_info.csv]
2026-01-13 emails for demonstration
    [LoRa_emails.csv, LoRa_emails.xlsx]
2026-01-13 Removed uncecessary files
    [LoRa_emails.csv, LoRa_emails.xlsx]
